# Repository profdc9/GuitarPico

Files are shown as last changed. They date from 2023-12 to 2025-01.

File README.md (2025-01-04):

# Guitar Pico

This is a guitar effects processor based on the Raspberry Pi Pico.  A video of some of the effects is at

https://www.youtube.com/watch?v=15d9mEu2koQ

It includes the following effects:

1.  Noise Gate
2.  Delay 
3.  Room (set up specific echoes at particular delays)
4.  Combine (mix together the signals from several effects)
5.  2nd order Bandpass filter
6.  2nd order Lowpass filter
7.  2nd order Highpass filter
8.  2nd order Allpass filter
9.  Tremolo (amplitude modulated by a low frequency oscillator)
10.  Vibrato (pitch modulated by a low frequency oscillator)
11.  Wah (bandpass filter with center frequency controlled by an external control like a pedal)
12.  AutoWah (bandpass filter with center frequency modulated by a low frequency oscillator)
13.  Envelope (bandpass filter with center frequency modulated by signal amplitude)
14.  Distortion (amplification resulting in saturation of the signal)
15.  Overdrive (selectable threshold for low signal / high signal amplitude gain)
16.  Compressor (amplifies weak signals to equal out overall amplitude of signal)
17.  Ring (ring modulator using low frequency oscillator)
18.  Flanger (pitch modulated by a low frequency oscillator, with feedback and combined with unmodulated signal)
19.  Chorus (pitch modulated by a low frequency oscillator, no feedback and combined with unmodulated signal)
20.  Phaser (signal run through multiple stages of all pass filters, combined with unmodulated signal)
21.  Backwards (plays the last samples backwards for weird swooping effect)
22.  PitchShift (allows shifting the pitch by variable amounts, useful for harmony-like effect)
23.  Whammy (pitch shift based on external control like a pedal)
24.  Octave (rectification and amplification of the signal with extreme distortion)
25.  Sinusoidal Oscillator (built in test signal source)

The effects may be cascaded, to up to 16 in a sequence.  The settings of a particular sequence of effects may be saved in flash memory.  Because the effects are processed one sample at a time in real-time, the lag due to the processing is only 50 microseconds.

There is a stomp pedal which may be used to one of four saved settings, based on which of the four buttons is stomped on.  It does not require power to operate.

The pedal has four potentiometers that may be assigned to control various aspects of effects operation.  There are also two external inputs.  These can be used with the stomp pedal, or with an expression pedal to control aspects of the effects.

There is also a feature to determine the frequency and note being played, to help with tuning a guitar.  Also, if plugged into USB, notes played on the guitar are sent as MIDI events to the PC to turn the guitar into a MIDI instruments.  However, this feature is imperfect (but this useful for tuning).

As well as a MIDI device, the guitar pedal appears as a COM port.  The effect settings may be retrieved from the pedal or programmed into the pedal through this interface using text commands at a prompt.  Type "HELP" for a list of the commands.  For example, typing "CONF 0 0" lists all of the current effects configuration data.  The data is output in the form of the commands used to reprogram the same state back into the device, so these may be directly copied into a text file and pasted back into a terminal to recreate the configuration.

There is also a VGA port that will be used to implement video effects.

The hardware is licensed under CC-BY-SA 4.0 and software under the zlib license (no warranty, yes commercial and noncommercial use), both open source licenses.

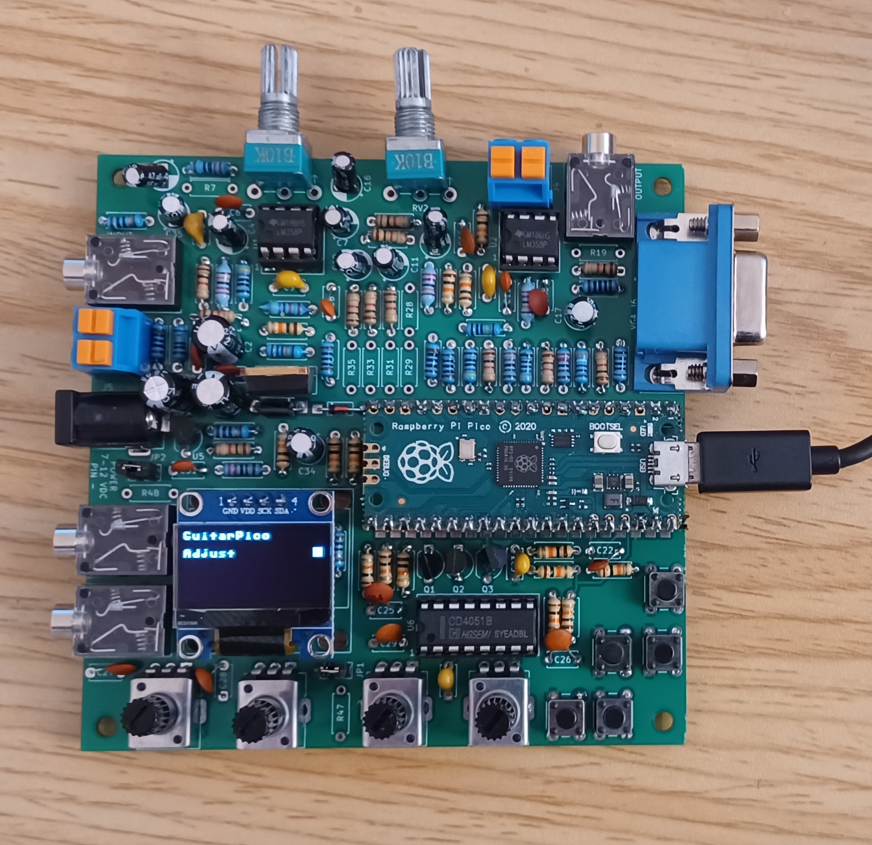
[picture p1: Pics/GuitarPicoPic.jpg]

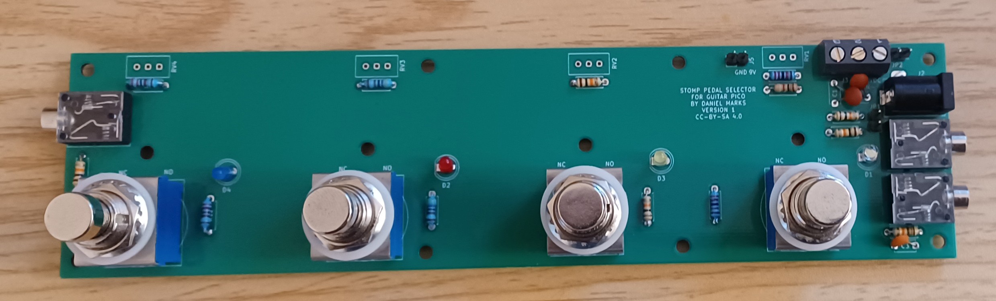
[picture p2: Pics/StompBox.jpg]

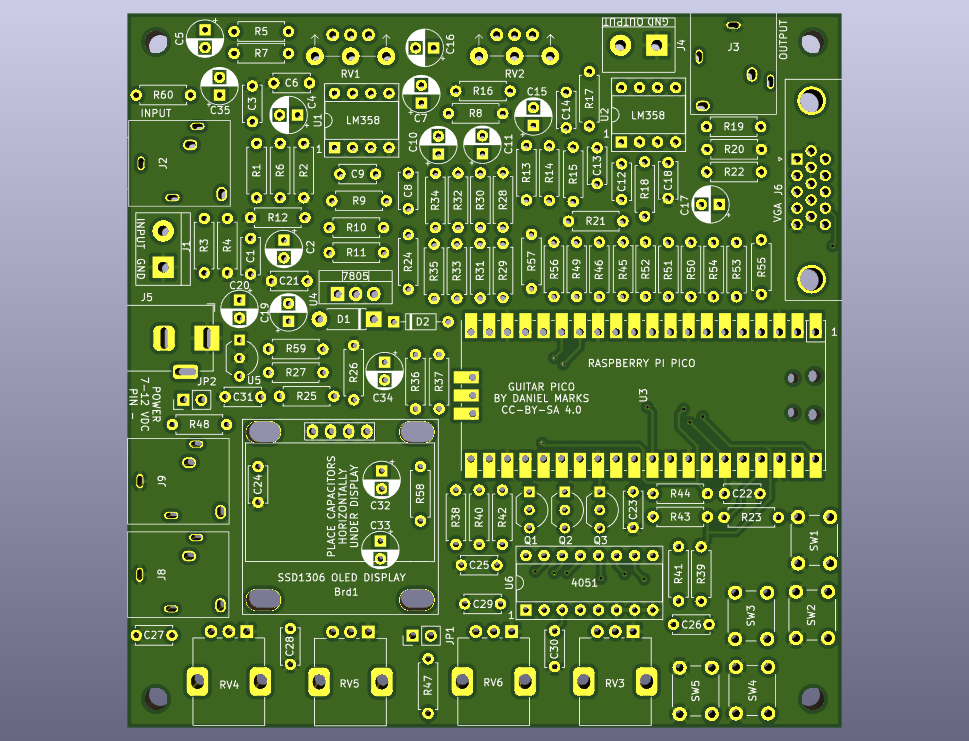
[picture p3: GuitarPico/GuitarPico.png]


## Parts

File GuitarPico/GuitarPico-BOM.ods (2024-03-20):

Source: | D:\projects\GuitarPico\GuitarPico\GuitarPico.kicad_sch
Date: | 03/10/24 08:09 PM
Tool: | Eeschema (6.0.11)
Generator: | C:\Program Files\KiCad\6.0\bin\scripting\plugins/bom_csv_grouped_by_value.py
Component Count: | 132
Individual Components:
Item / lcsc.com | Qty | Reference(s) | Value | LibPart | Footprint | Datasheet
 |  | Brd1 | SSD1306 | SSD1306-128x64_OLED:SSD1306 | GuitarPico:128x64OLED
C2832508 |  | C1 | 100 nF | Device:C_Small | Capacitor_THT:C_Disc_D5.0mm_W2.5mm_P5.00mm | ~
C6718384 |  | C2 | 100 uF | Device:C_Polarized_Small | Capacitor_THT:CP_Radial_D5.0mm_P2.50mm | ~
C2761726 |  | C3 | 1000 pF | Device:C_Small | Capacitor_THT:C_Disc_D5.0mm_W2.5mm_P5.00mm | ~
C106654 |  | C4 | 10 uF | Device:C_Polarized_Small | Capacitor_THT:CP_Radial_D5.0mm_P2.50mm | ~
C106654 |  | C5 | 10 uF | Device:C_Polarized_Small | Capacitor_THT:CP_Radial_D5.0mm_P2.50mm | ~
C2832508 |  | C6 | 100 nF | Device:C_Small | Capacitor_THT:C_Disc_D5.0mm_W2.5mm_P5.00mm | ~
C106654 |  | C7 | 10 uF | Device:C_Polarized_Small | Capacitor_THT:CP_Radial_D5.0mm_P2.50mm | ~
C2887269 |  | C8 | 2200 pF | Device:C_Small | Capacitor_THT:C_Disc_D5.0mm_W2.5mm_P5.00mm | ~
C2896128 |  | C9 | 220 pF | Device:C_Small | Capacitor_THT:C_Disc_D5.0mm_W2.5mm_P5.00mm | ~
C106654 |  | C10 | 10 uF | Device:C_Polarized_Small | Capacitor_THT:CP_Radial_D5.0mm_P2.50mm | ~
C106654 |  | C11 | 10 uF | Device:C_Polarized_Small | Capacitor_THT:CP_Radial_D5.0mm_P2.50mm | ~
C2887269 |  | C12 | 2200 pF | Device:C_Small | Capacitor_THT:C_Disc_D5.0mm_W2.5mm_P5.00mm | ~
C2896103 |  | C13 | 470 pF | Device:C_Small | Capacitor_THT:C_Disc_D5.0mm_W2.5mm_P5.00mm | ~
C2832508 |  | C14 | 100 nF | Device:C_Small | Capacitor_THT:C_Disc_D5.0mm_W2.5mm_P5.00mm | ~
C106654 |  | C15 | 10 uF | Device:C_Polarized_Small | Capacitor_THT:CP_Radial_D5.0mm_P2.50mm | ~
C106654 |  | C16 | 10 uF | Device:C_Polarized_Small | Capacitor_THT:CP_Radial_D5.0mm_P2.50mm | ~
C106654 |  | C17 | 10 uF | Device:C_Polarized_Small | Capacitor_THT:CP_Radial_D5.0mm_P2.50mm | ~
C2832508 |  | C18 | 100 nF | Device:C_Small | Capacitor_THT:C_Disc_D5.0mm_W2.5mm_P5.00mm | ~
C6718384 |  | C19 | 100 uF | Device:C_Polarized_Small | Capacitor_THT:CP_Radial_D5.0mm_P2.50mm | ~
C6718384 |  | C20 | 100 uF | Device:C_Polarized_Small | Capacitor_THT:CP_Radial_D5.0mm_P2.50mm | ~
C2832508 |  | C21 | 100 nF | Device:C_Small | Capacitor_THT:C_Disc_D5.0mm_W2.5mm_P5.00mm | ~
C2761727 |  | C22 | 10 nF | Device:C_Small | Capacitor_THT:C_Disc_D5.0mm_W2.5mm_P5.00mm | ~
C2761725 |  | C23 | 100 pF | Device:C_Small | Capacitor_THT:C_Disc_D5.0mm_W2.5mm_P5.00mm | ~
C2832508 |  | C24 | 100 nF | Device:C_Small | Capacitor_THT:C_Disc_D5.0mm_W2.5mm_P5.00mm | ~
C2832508 |  | C25 | 100 nF | Device:C_Small | Capacitor_THT:C_Disc_D5.0mm_W2.5mm_P5.00mm | ~
C2832508 |  | C26 | 100 nF | Device:C_Small | Capacitor_THT:C_Disc_D5.0mm_W2.5mm_P5.00mm | ~
C2832508 |  | C27 | 100 nF | Device:C_Small | Capacitor_THT:C_Disc_D5.0mm_W2.5mm_P5.00mm | ~
C2832508 |  | C28 | 100 nF | Device:C_Small | Capacitor_THT:C_Disc_D5.0mm_W2.5mm_P5.00mm | ~
C2832508 |  | C29 | 100 nF | Device:C_Small | Capacitor_THT:C_Disc_D5.0mm_W2.5mm_P5.00mm | ~
C2761725 |  | C30 | 100 pF | Device:C_Small | Capacitor_THT:C_Disc_D5.0mm_W2.5mm_P5.00mm | ~
C2761727 |  | C31 | 10 nF | Device:C_Small | Capacitor_THT:C_Disc_D5.0mm_W2.5mm_P5.00mm | ~
C141282 |  | C32 | 220 uF | Device:C_Polarized_Small | Capacitor_THT:CP_Radial_D5.0mm_P2.50mm | ~
C141282 |  | C33 | 220 uF | Device:C_Polarized_Small | Capacitor_THT:CP_Radial_D5.0mm_P2.50mm | ~
C6718384 |  | C34 | 100 uF | Device:C_Polarized_Small | Capacitor_THT:CP_Radial_D5.0mm_P2.50mm | ~
C6718384 |  | C35 | 100 uF | Device:C_Polarized_Small | Capacitor_THT:CP_Radial_D5.0mm_P2.50mm | ~
C5295404 |  | D1 | 1N5819 | Device:D_Schottky | Diode_THT:D_DO-41_SOD81_P7.62mm_Horizontal | ~
C402212 |  | D2 | 1N4148 | Device:D | Diode_THT:D_DO-35_SOD27_P7.62mm_Horizontal | ~
C2915639 |  | J1 | INPUT | Connector_Generic:Conn_01x02 | TerminalBlock:TerminalBlock_bornier-2_P5.08mm | ~
C145814 |  | J2 | INPUT | Connector:AudioJack2_Dual_Ground_Switch | GuitarPico:PJ-3240-35mm-stereo | ~
C145814 |  | J3 | OUTPUT | Connector:AudioJack2_Dual_Ground_Switch | GuitarPico:PJ-3240-35mm-stereo | ~
C2915639 |  | J4 | OUTPUT | Connector_Generic:Conn_01x02 | TerminalBlock:TerminalBlock_bornier-2_P5.08mm | ~
C16214 |  | J5 | Barrel_Jack_Switch | Connector:Barrel_Jack_Switch | Connector_BarrelJack:BarrelJack_Horizontal | ~
C379814 |  | J6 | VGA | Connector:DB15_Female_HighDensity | Connector_Dsub:DSUB-15-HD_Female_Horizontal_P2.29x1.98mm_EdgePinOffset3.03mm_Housed_MountingHolesOffset4.94mm | ~
C145814 |  | J8 | INPUT | Connector:AudioJack2_Dual_Ground_Switch | GuitarPico:PJ-3240-35mm-stereo | ~
C145814 |  | J9 | INPUT | Connector:AudioJack2_Dual_Ground_Switch | GuitarPico:PJ-3240-35mm-stereo | ~
C429959 |  | JP1 | POWER | Jumper:Jumper_2_Open | Connector_PinHeader_2.54mm:PinHeader_1x02_P2.54mm_Vertical | ~
C429959 |  | JP2 | POWER | Jumper:Jumper_2_Open | Connector_PinHeader_2.54mm:PinHeader_1x02_P2.54mm_Vertical | ~
C305395 |  | Q1 | 2N3904 | Transistor_BJT:2N3904 | Package_TO_SOT_THT:TO-92_Inline_Wide | https://www.onsemi.com/pub/Collateral/2N3903-D.PDF
C305395 |  | Q2 | 2N3904 | Transistor_BJT:2N3904 | Package_TO_SOT_THT:TO-92_Inline_Wide | https://www.onsemi.com/pub/Collateral/2N3903-D.PDF
C305395 |  | Q3 | 2N3904 | Transistor_BJT:2N3904 | Package_TO_SOT_THT:TO-92_Inline_Wide | https://www.onsemi.com/pub/Collateral/2N3903-D.PDF
C713997 |  | R1 | 1k | Device:R | Resistor_THT:R_Axial_DIN0207_L6.3mm_D2.5mm_P7.62mm_Horizontal | ~
C119317 (https://www.lcsc.com/product-detail/Through-Hole-Resistors_CCO-Chian-Chia-Elec-MF1-4W-470-1-T_C119317.html) |  | R2 | 470R | Device:R | Resistor_THT:R_Axial_DIN0207_L6.3mm_D2.5mm_P7.62mm_Horizontal | ~
C57438 (https://www.lcsc.com/product-detail/Through-Hole-Resistors_UNI-ROYAL-Uniroyal-Elec-MFR0W4F1000A50_C57438.html) |  | R3 | 100R | Device:R | Resistor_THT:R_Axial_DIN0207_L6.3mm_D2.5mm_P7.62mm_Horizontal | ~
C714052 (https://www.lcsc.com/product-detail/Through-Hole-Resistors_Huaxing-Mechanical-Elec-MF1-4W-1M-1-T52_C714052.html) |  | R4 | 1M | Device:R | Resistor_THT:R_Axial_DIN0207_L6.3mm_D2.5mm_P7.62mm_Horizontal | ~
C120039 (https://www.lcsc.com/product-detail/Through-Hole-Resistors_CCO-Chian-Chia-Elec-CF1-4W-220-5-T_C120039.html) |  | R5 | 220R | Device:R | Resistor_THT:R_Axial_DIN0207_L6.3mm_D2.5mm_P7.62mm_Horizontal | ~
C58662 (https://www.lcsc.com/product-detail/Through-Hole-Resistors_UNI-ROYAL-Uniroyal-Elec-MFR0W4F2203A50_C58662.html) |  | R6 | 220k | Device:R | Resistor_THT:R_Axial_DIN0207_L6.3mm_D2.5mm_P7.62mm_Horizontal | ~
 |  | R7 | NC | Device:R | Resistor_THT:R_Axial_DIN0207_L6.3mm_D2.5mm_P7.62mm_Horizontal | ~
C713997 |  | R8 | 1k | Device:R | Resistor_THT:R_Axial_DIN0207_L6.3mm_D2.5mm_P7.62mm_Horizontal | ~
C176519 (https://www.lcsc.com/product-detail/Through-Hole-Resistors_YAGEO-MFR-25JT-52-47K_C176519.html) |  | R9 | 47k | Device:R | Resistor_THT:R_Axial_DIN0207_L6.3mm_D2.5mm_P7.62mm_Horizontal | ~
C410695 (https://www.lcsc.com/product-detail/Through-Hole-Resistors_TyoHM-RN1-4W10KFT-BA1_C410695.html) |  | R10 | 10k | Device:R | Resistor_THT:R_Axial_DIN0207_L6.3mm_D2.5mm_P7.62mm_Horizontal | ~
C61303 (https://www.lcsc.com/product-detail/Through-Hole-Resistors_UNI-ROYAL-Uniroyal-Elec-CFR0W4J0104A50_C61303.html) |  | R11 | 100k | Device:R | Resistor_THT:R_Axial_DIN0207_L6.3mm_D2.5mm_P7.62mm_Horizontal | ~
C713997 |  | R12 | 1k | Device:R | Resistor_THT:R_Axial_DIN0207_L6.3mm_D2.5mm_P7.62mm_Horizontal | ~
C58662 (https://www.lcsc.com/product-detail/Through-Hole-Resistors_UNI-ROYAL-Uniroyal-Elec-MFR0W4F2203A50_C58662.html) |  | R13 | 220k | Device:R | Resistor_THT:R_Axial_DIN0207_L6.3mm_D2.5mm_P7.62mm_Horizontal | ~
C410695 (https://www.lcsc.com/product-detail/Through-Hole-Resistors_TyoHM-RN1-4W10KFT-BA1_C410695.html) |  | R14 | 10k | Device:R | Resistor_THT:R_Axial_DIN0207_L6.3mm_D2.5mm_P7.62mm_Horizontal | ~
C410695 (https://www.lcsc.com/product-detail/Through-Hole-Resistors_TyoHM-RN1-4W10KFT-BA1_C410695.html) |  | R15 | 10k | Device:R | Resistor_THT:R_Axial_DIN0207_L6.3mm_D2.5mm_P7.62mm_Horizontal | ~
C713997 |  | R16 | 1k | Device:R | Resistor_THT:R_Axial_DIN0207_L6.3mm_D2.5mm_P7.62mm_Horizontal | ~
C410695 (https://www.lcsc.com/product-detail/Through-Hole-Resistors_TyoHM-RN1-4W10KFT-BA1_C410695.html) |  | R17 | 10k | Device:R | Resistor_THT:R_Axial_DIN0207_L6.3mm_D2.5mm_P7.62mm_Horizontal | ~
C58662 (https://www.lcsc.com/product-detail/Through-Hole-Resistors_UNI-ROYAL-Uniroyal-Elec-MFR0W4F2203A50_C58662.html) |  | R18 | 220k | Device:R | Resistor_THT:R_Axial_DIN0207_L6.3mm_D2.5mm_P7.62mm_Horizontal | ~
NC |  | R19 | NC | Device:R | Resistor_THT:R_Axial_DIN0207_L6.3mm_D2.5mm_P7.62mm_Horizontal | ~
C713997 |  | R20 | 1k | Device:R | Resistor_THT:R_Axial_DIN0207_L6.3mm_D2.5mm_P7.62mm_Horizontal | ~
C714052 (https://www.lcsc.com/product-detail/Through-Hole-Resistors_Huaxing-Mechanical-Elec-MF1-4W-1M-1-T52_C714052.html) |  | R21 | 1M | Device:R | Resistor_THT:R_Axial_DIN0207_L6.3mm_D2.5mm_P7.62mm_Horizontal | ~
C57438 (https://www.lcsc.com/product-detail/Through-Hole-Resistors_UNI-ROYAL-Uniroyal-Elec-MFR0W4F1000A50_C57438.html) |  | R22 | 100R | Device:R | Resistor_THT:R_Axial_DIN0207_L6.3mm_D2.5mm_P7.62mm_Horizontal | ~
C410695 (https://www.lcsc.com/product-detail/Through-Hole-Resistors_TyoHM-RN1-4W10KFT-BA1_C410695.html) |  | R23 | 10k | Device:R | Resistor_THT:R_Axial_DIN0207_L6.3mm_D2.5mm_P7.62mm_Horizontal | ~
C57438 (https://www.lcsc.com/product-detail/Through-Hole-Resistors_UNI-ROYAL-Uniroyal-Elec-MFR0W4F1000A50_C57438.html) |  | R24 | 100R | Device:R | Resistor_THT:R_Axial_DIN0207_L6.3mm_D2.5mm_P7.62mm_Horizontal | ~
C58595 (https://www.lcsc.com/product-detail/Through-Hole-Resistors_UNI-ROYAL-Uniroyal-Elec-MFR0W4F2201A50_C58595.html) |  | R25 | 2k2 | Device:R | Resistor_THT:R_Axial_DIN0207_L6.3mm_D2.5mm_P7.62mm_Horizontal | ~
C410695 (https://www.lcsc.com/product-detail/Through-Hole-Resistors_TyoHM-RN1-4W10KFT-BA1_C410695.html) |  | R26 | 10k | Device:R | Resistor_THT:R_Axial_DIN0207_L6.3mm_D2.5mm_P7.62mm_Horizontal | ~
C713997 |  | R27 | 1k | Device:R | Resistor_THT:R_Axial_DIN0207_L6.3mm_D2.5mm_P7.62mm_Horizontal | ~
C119330 (https://www.lcsc.com/product-detail/Through-Hole-Resistors_CCO-Chian-Chia-Elec-MF1-4W-2K-1-T_C119330.html) |  | R28 | 2k | Device:R | Resistor_THT:R_Axial_DIN0207_L6.3mm_D2.5mm_P7.62mm_Horizontal | ~
C119330 (https://www.lcsc.com/product-detail/Through-Hole-Resistors_CCO-Chian-Chia-Elec-MF1-4W-2K-1-T_C119330.html) |  | R29 | 2k | Device:R | Resistor_THT:R_Axial_DIN0207_L6.3mm_D2.5mm_P7.62mm_Horizontal | ~
C713997 |  | R30 | 1k | Device:R | Resistor_THT:R_Axial_DIN0207_L6.3mm_D2.5mm_P7.62mm_Horizontal | ~
C119330 (https://www.lcsc.com/product-detail/Through-Hole-Resistors_CCO-Chian-Chia-Elec-MF1-4W-2K-1-T_C119330.html) |  | R31 | 2k | Device:R | Resistor_THT:R_Axial_DIN0207_L6.3mm_D2.5mm_P7.62mm_Horizontal | ~
C713997 |  | R32 | 1k | Device:R | Resistor_THT:R_Axial_DIN0207_L6.3mm_D2.5mm_P7.62mm_Horizontal | ~
C119330 (https://www.lcsc.com/product-detail/Through-Hole-Resistors_CCO-Chian-Chia-Elec-MF1-4W-2K-1-T_C119330.html) |  | R33 | 2k | Device:R | Resistor_THT:R_Axial_DIN0207_L6.3mm_D2.5mm_P7.62mm_Horizontal | ~
C713997 |  | R34 | 1k | Device:R | Resistor_THT:R_Axial_DIN0207_L6.3mm_D2.5mm_P7.62mm_Horizontal | ~
C119330 (https://www.lcsc.com/product-detail/Through-Hole-Resistors_CCO-Chian-Chia-Elec-MF1-4W-2K-1-T_C119330.html) |  | R35 | 2k | Device:R | Resistor_THT:R_Axial_DIN0207_L6.3mm_D2.5mm_P7.62mm_Horizontal | ~
C410695 (https://www.lcsc.com/product-detail/Through-Hole-Resistors_TyoHM-RN1-4W10KFT-BA1_C410695.html) |  | R36 | 10k | Device:R | Resistor_THT:R_Axial_DIN0207_L6.3mm_D2.5mm_P7.62mm_Horizontal | ~
C410695 (https://www.lcsc.com/product-detail/Through-Hole-Resistors_TyoHM-RN1-4W10KFT-BA1_C410695.html) |  | R37 | 10k | Device:R | Resistor_THT:R_Axial_DIN0207_L6.3mm_D2.5mm_P7.62mm_Horizontal | ~
C410695 (https://www.lcsc.com/product-detail/Through-Hole-Resistors_TyoHM-RN1-4W10KFT-BA1_C410695.html) |  | R38 | 10k | Device:R | Resistor_THT:R_Axial_DIN0207_L6.3mm_D2.5mm_P7.62mm_Horizontal | ~
C410695 (https://www.lcsc.com/product-detail/Through-Hole-Resistors_TyoHM-RN1-4W10KFT-BA1_C410695.html) |  | R39 | 10k | Device:R | Resistor_THT:R_Axial_DIN0207_L6.3mm_D2.5mm_P7.62mm_Horizontal | ~
C410695 (https://www.lcsc.com/product-detail/Through-Hole-Resistors_TyoHM-RN1-4W10KFT-BA1_C410695.html) |  | R40 | 10k | Device:R | Resistor_THT:R_Axial_DIN0207_L6.3mm_D2.5mm_P7.62mm_Horizontal | ~
C410695 (https://www.lcsc.com/product-detail/Through-Hole-Resistors_TyoHM-RN1-4W10KFT-BA1_C410695.html) |  | R41 | 10k | Device:R | Resistor_THT:R_Axial_DIN0207_L6.3mm_D2.5mm_P7.62mm_Horizontal | ~
C410695 (https://www.lcsc.com/product-detail/Through-Hole-Resistors_TyoHM-RN1-4W10KFT-BA1_C410695.html) |  | R42 | 10k | Device:R | Resistor_THT:R_Axial_DIN0207_L6.3mm_D2.5mm_P7.62mm_Horizontal | ~
C410695 (https://www.lcsc.com/product-detail/Through-Hole-Resistors_TyoHM-RN1-4W10KFT-BA1_C410695.html) |  | R43 | 10k | Device:R | Resistor_THT:R_Axial_DIN0207_L6.3mm_D2.5mm_P7.62mm_Horizontal | ~
C410695 (https://www.lcsc.com/product-detail/Through-Hole-Resistors_TyoHM-RN1-4W10KFT-BA1_C410695.html) |  | R44 | 10k | Device:R | Resistor_THT:R_Axial_DIN0207_L6.3mm_D2.5mm_P7.62mm_Horizontal | ~
C58595 (https://www.lcsc.com/product-detail/Through-Hole-Resistors_UNI-ROYAL-Uniroyal-Elec-MFR0W4F2201A50_C58595.html) |  | R45 | 2k2 | Device:R | Resistor_THT:R_Axial_DIN0207_L6.3mm_D2.5mm_P7.62mm_Horizontal | ~
C713997 |  | R46 | 1k | Device:R | Resistor_THT:R_Axial_DIN0207_L6.3mm_D2.5mm_P7.62mm_Horizontal | ~
NC |  | R47 | NC | Device:R | Resistor_THT:R_Axial_DIN0207_L6.3mm_D2.5mm_P7.62mm_Horizontal | ~
NC |  | R48 | NC | Device:R | Resistor_THT:R_Axial_DIN0207_L6.3mm_D2.5mm_P7.62mm_Horizontal | ~
C119317 (https://www.lcsc.com/product-detail/Through-Hole-Resistors_CCO-Chian-Chia-Elec-MF1-4W-470-1-T_C119317.html) |  | R49 | 470R | Device:R | Resistor_THT:R_Axial_DIN0207_L6.3mm_D2.5mm_P7.62mm_Horizontal | ~
C58595 (https://www.lcsc.com/product-detail/Through-Hole-Resistors_UNI-ROYAL-Uniroyal-Elec-MFR0W4F2201A50_C58595.html) |  | R50 | 2k2 | Device:R | Resistor_THT:R_Axial_DIN0207_L6.3mm_D2.5mm_P7.62mm_Horizontal | ~
C713997 |  | R51 | 1k | Device:R | Resistor_THT:R_Axial_DIN0207_L6.3mm_D2.5mm_P7.62mm_Horizontal | ~
C119317 (https://www.lcsc.com/product-detail/Through-Hole-Resistors_CCO-Chian-Chia-Elec-MF1-4W-470-1-T_C119317.html) |  | R52 | 470R | Device:R | Resistor_THT:R_Axial_DIN0207_L6.3mm_D2.5mm_P7.62mm_Horizontal | ~
C713997 |  | R53 | 1k | Device:R | Resistor_THT:R_Axial_DIN0207_L6.3mm_D2.5mm_P7.62mm_Horizontal | ~
C173010 (https://www.lcsc.com/product-detail/Through-Hole-Resistors_YAGEO-MFR-25FTE52-390R_C173010.html) |  | R54 | 390R | Device:R | Resistor_THT:R_Axial_DIN0207_L6.3mm_D2.5mm_P7.62mm_Horizontal | ~
C58668 (https://www.lcsc.com/product-detail/Through-Hole-Resistors_UNI-ROYAL-Uniroyal-Elec-MFR0W4F1500A50_C58668.html) |  | R55 | 150R | Device:R | Resistor_THT:R_Axial_DIN0207_L6.3mm_D2.5mm_P7.62mm_Horizontal | ~
C57438 (https://www.lcsc.com/product-detail/Through-Hole-Resistors_UNI-ROYAL-Uniroyal-Elec-MFR0W4F1000A50_C57438.html) |  | R56 | 100R | Device:R | Resistor_THT:R_Axial_DIN0207_L6.3mm_D2.5mm_P7.62mm_Horizontal | ~
C57438 (https://www.lcsc.com/product-detail/Through-Hole-Resistors_UNI-ROYAL-Uniroyal-Elec-MFR0W4F1000A50_C57438.html) |  | R57 | 100R | Device:R | Resistor_THT:R_Axial_DIN0207_L6.3mm_D2.5mm_P7.62mm_Horizontal | ~
C119282 (https://www.lcsc.com/product-detail/Through-Hole-Resistors_CCO-Chian-Chia-Elec-MF1-4W-10-1-T_C119282.html) |  | R58 | 10R | Device:R | Resistor_THT:R_Axial_DIN0207_L6.3mm_D2.5mm_P7.62mm_Horizontal | ~
C119282 (https://www.lcsc.com/product-detail/Through-Hole-Resistors_CCO-Chian-Chia-Elec-MF1-4W-10-1-T_C119282.html) |  | R59 | 10R | Device:R | Resistor_THT:R_Axial_DIN0207_L6.3mm_D2.5mm_P7.62mm_Horizontal | ~
C119282 (https://www.lcsc.com/product-detail/Through-Hole-Resistors_CCO-Chian-Chia-Elec-MF1-4W-10-1-T_C119282.html) |  | R60 | 10R | Device:R | Resistor_THT:R_Axial_DIN0207_L6.3mm_D2.5mm_P7.62mm_Horizontal | ~
C470717 |  | RV1 | 10k | Device:R_Potentiometer | GuitarPico:Potentiometer_Big_Small_Combined | ~
C470717 |  | RV2 | 10k | Device:R_Potentiometer | GuitarPico:Potentiometer_Big_Small_Combined | ~
C209779 |  | RV3 | 10k | Device:R_Potentiometer | Potentiometer_THT:Potentiometer_Alps_RK09K_Single_Vertical | ~
C209779 |  | RV4 | 10k | Device:R_Potentiometer | Potentiometer_THT:Potentiometer_Alps_RK09K_Single_Vertical | ~
C209779 |  | RV5 | 10k | Device:R_Potentiometer | Potentiometer_THT:Potentiometer_Alps_RK09K_Single_Vertical | ~
C209779 |  | RV6 | 10k | Device:R_Potentiometer | Potentiometer_THT:Potentiometer_Alps_RK09K_Single_Vertical | ~
C319408 |  | SW1 | SW_Push | Switch:SW_Push | Button_Switch_THT:SW_PUSH_6mm | ~
C319408 |  | SW2 | SW_Push | Switch:SW_Push | Button_Switch_THT:SW_PUSH_6mm | ~
C319408 |  | SW3 | SW_Push | Switch:SW_Push | Button_Switch_THT:SW_PUSH_6mm | ~
C319408 |  | SW4 | SW_Push | Switch:SW_Push | Button_Switch_THT:SW_PUSH_6mm | ~
C319408 |  | SW5 | SW_Push | Switch:SW_Push | Button_Switch_THT:SW_PUSH_6mm | ~
C434570,C72124 |  | U1 | LM358 | Amplifier_Operational:LM358 | Package_DIP:DIP-8_W7.62mm_Socket | http://www.ti.com/lit/ds/symlink/lm2904-n.pdf
C434570,C72124 |  | U2 | LM358 | Amplifier_Operational:LM358 | Package_DIP:DIP-8_W7.62mm_Socket | http://www.ti.com/lit/ds/symlink/lm2904-n.pdf
C343636 |  | U3 | Pico | MCU_RaspberryPi_and_Boards:Pico | GuitarPico:RPi_Pico_SMD_TH
C7432180 |  | U4 | LM7805_TO220 | Regulator_Linear:LM7805_TO220 | Package_TO_SOT_THT:TO-220-3_Vertical | https://www.onsemi.cn/PowerSolutions/document/MC7800-D.PDF
C5155530 |  | U5 | TL431LP | Reference_Voltage:TL431LP | Package_TO_SOT_THT:TO-92_Inline_Wide | http://www.ti.com/lit/ds/symlink/tl431.pdf
C507164,C72115 |  | U6 | 4051 | 4xxx:4051 | Package_DIP:DIP-16_W7.62mm_Socket | http://www.intersil.com/content/dam/Intersil/documents/cd40/cd4051bms-52bms-53bms.pdf

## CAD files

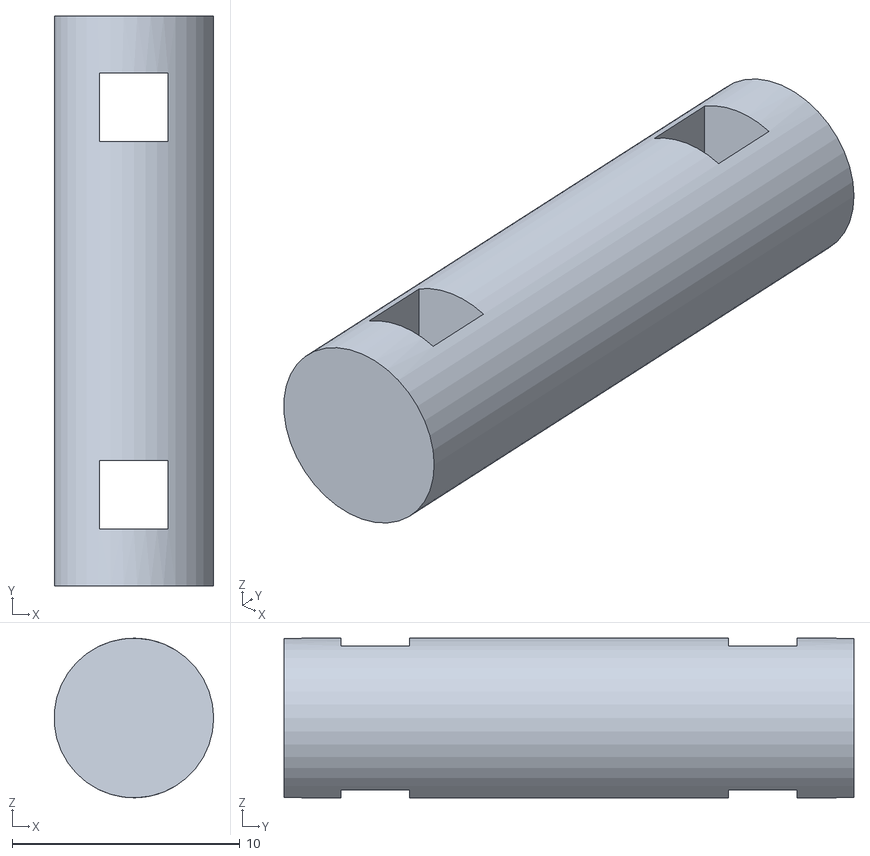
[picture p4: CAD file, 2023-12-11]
CAD/GuitarPedal-PivotRodRight.stl
6.99 x 25.0 x 7.00

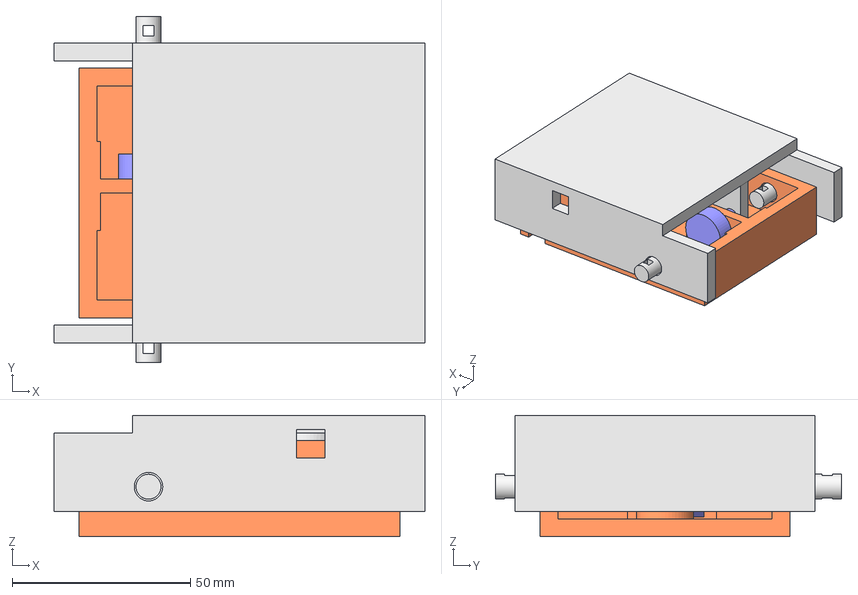
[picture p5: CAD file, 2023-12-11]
CAD/GuitarPedal.FCStd
104.0 x 97.0 x 34.0 mm
PivotRodLeft
PivotRodRight
Potentiometer
TopPedal
BottomPedal

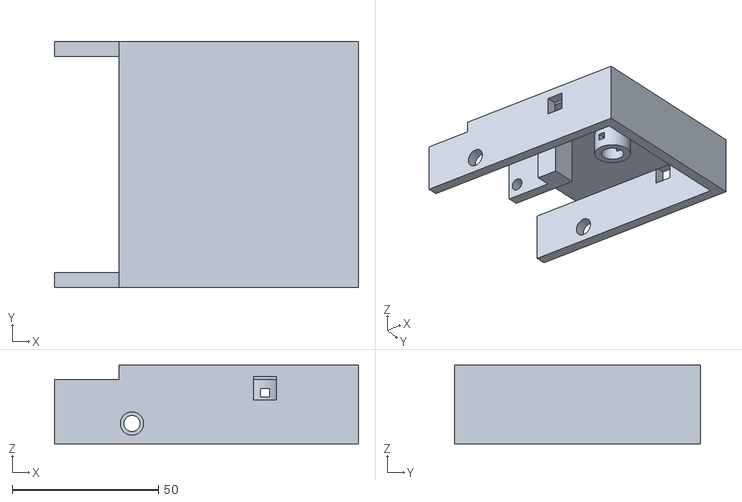
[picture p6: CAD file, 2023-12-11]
CAD/GuitarPedal-TopPedal.stl
104.0 x 84.0 x 27.0

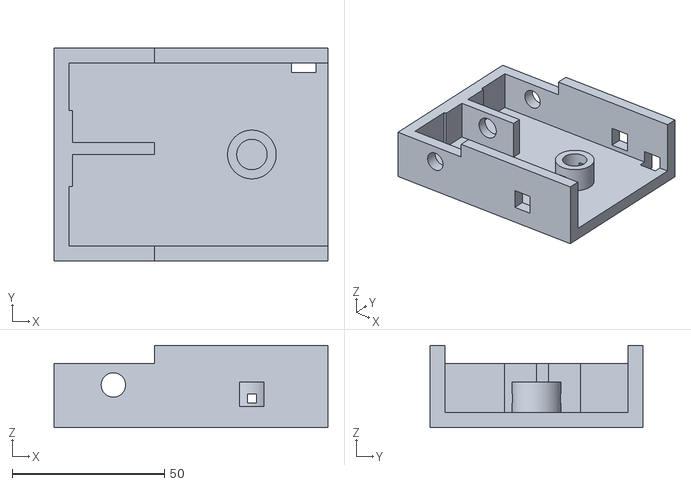
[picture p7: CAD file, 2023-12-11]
CAD/GuitarPedal-BottomPedal.stl
90.0 x 70.0 x 27.0

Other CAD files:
CAD/GuitarPedal-PivotRodLeft.stl

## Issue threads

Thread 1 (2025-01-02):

Build fails - Update needed?

engrjones, 2025-01-02:
I recently tried to build the solution and ran into some issues. I got it to work with some simple fixes. It's possible I just didn't have the right environment or something, but here's what I did, in case it's helpful:

1. Add `#include "hardware/clocks.h"` to main.cpp and vga_mode.cpp. The solution would not build without this addition.
2. In dsp.c Line 33, change `"Waves.h"` to `"waves.h"`.

profdc9, 2025-01-03:
I recently made those changes with the new Development Tools and I will
push them up shortly.   Also the TrebleSynth has the fixes too.

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

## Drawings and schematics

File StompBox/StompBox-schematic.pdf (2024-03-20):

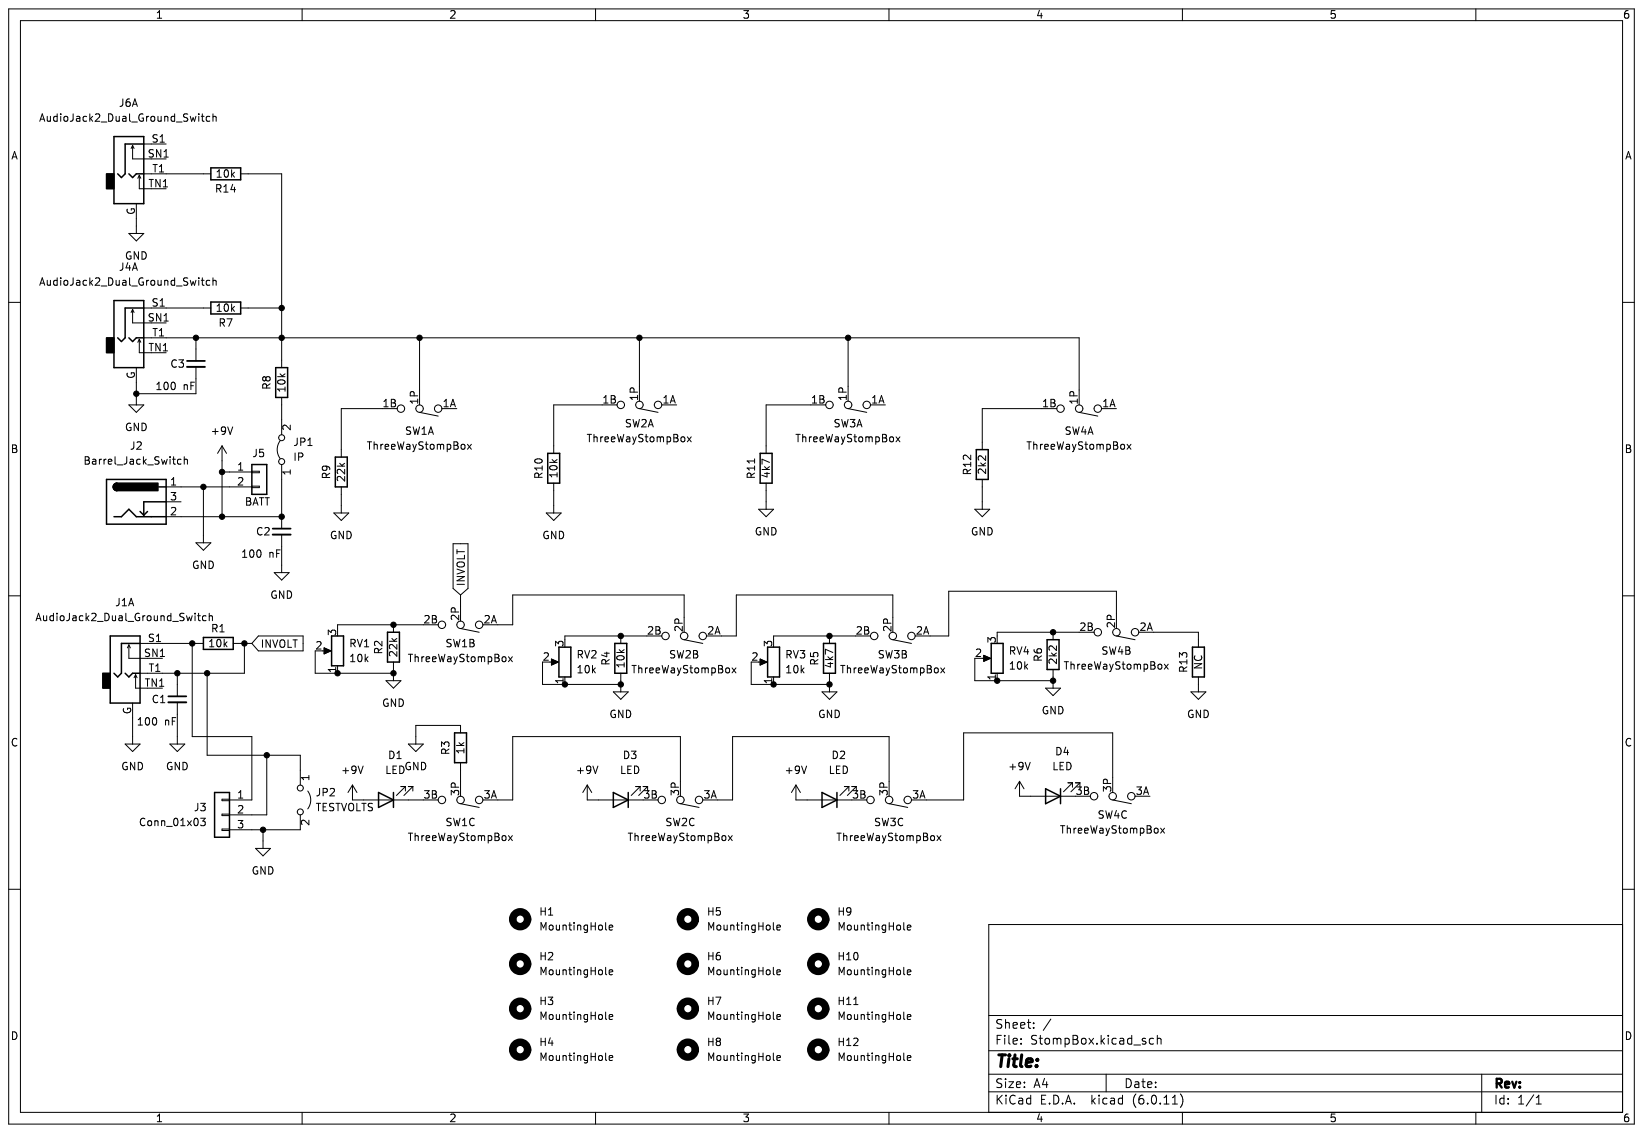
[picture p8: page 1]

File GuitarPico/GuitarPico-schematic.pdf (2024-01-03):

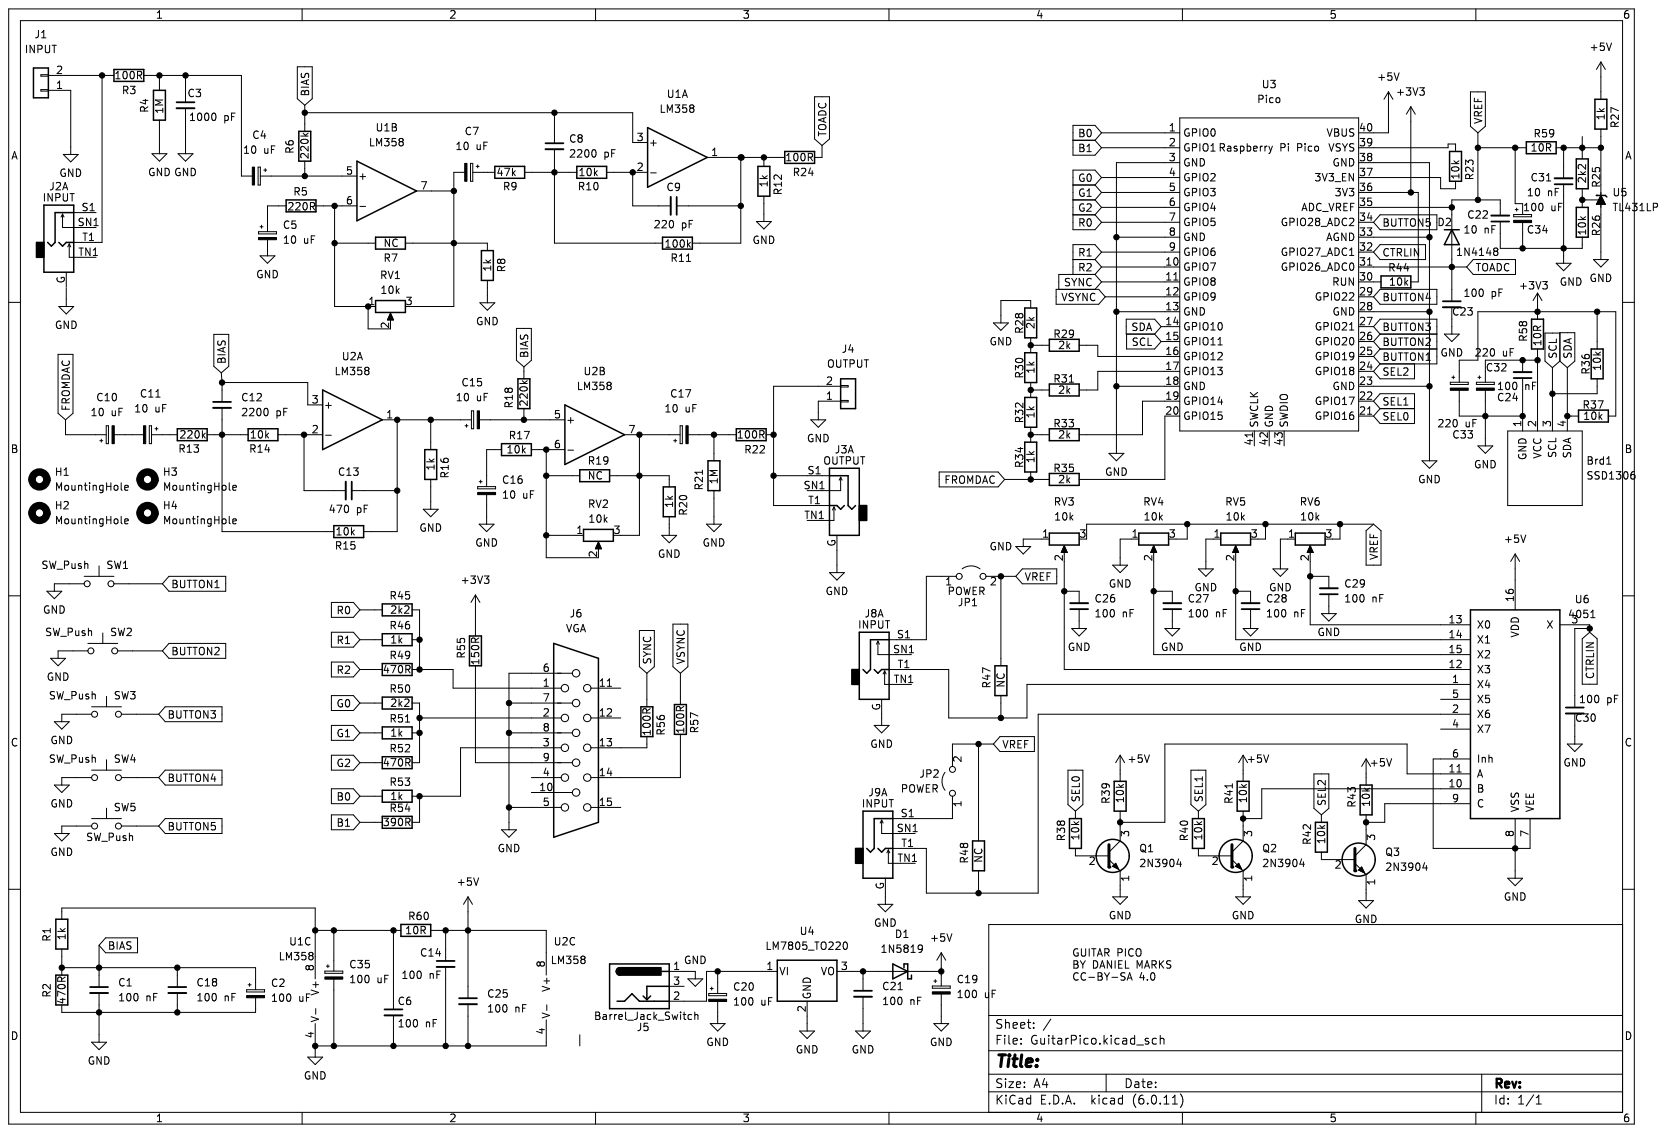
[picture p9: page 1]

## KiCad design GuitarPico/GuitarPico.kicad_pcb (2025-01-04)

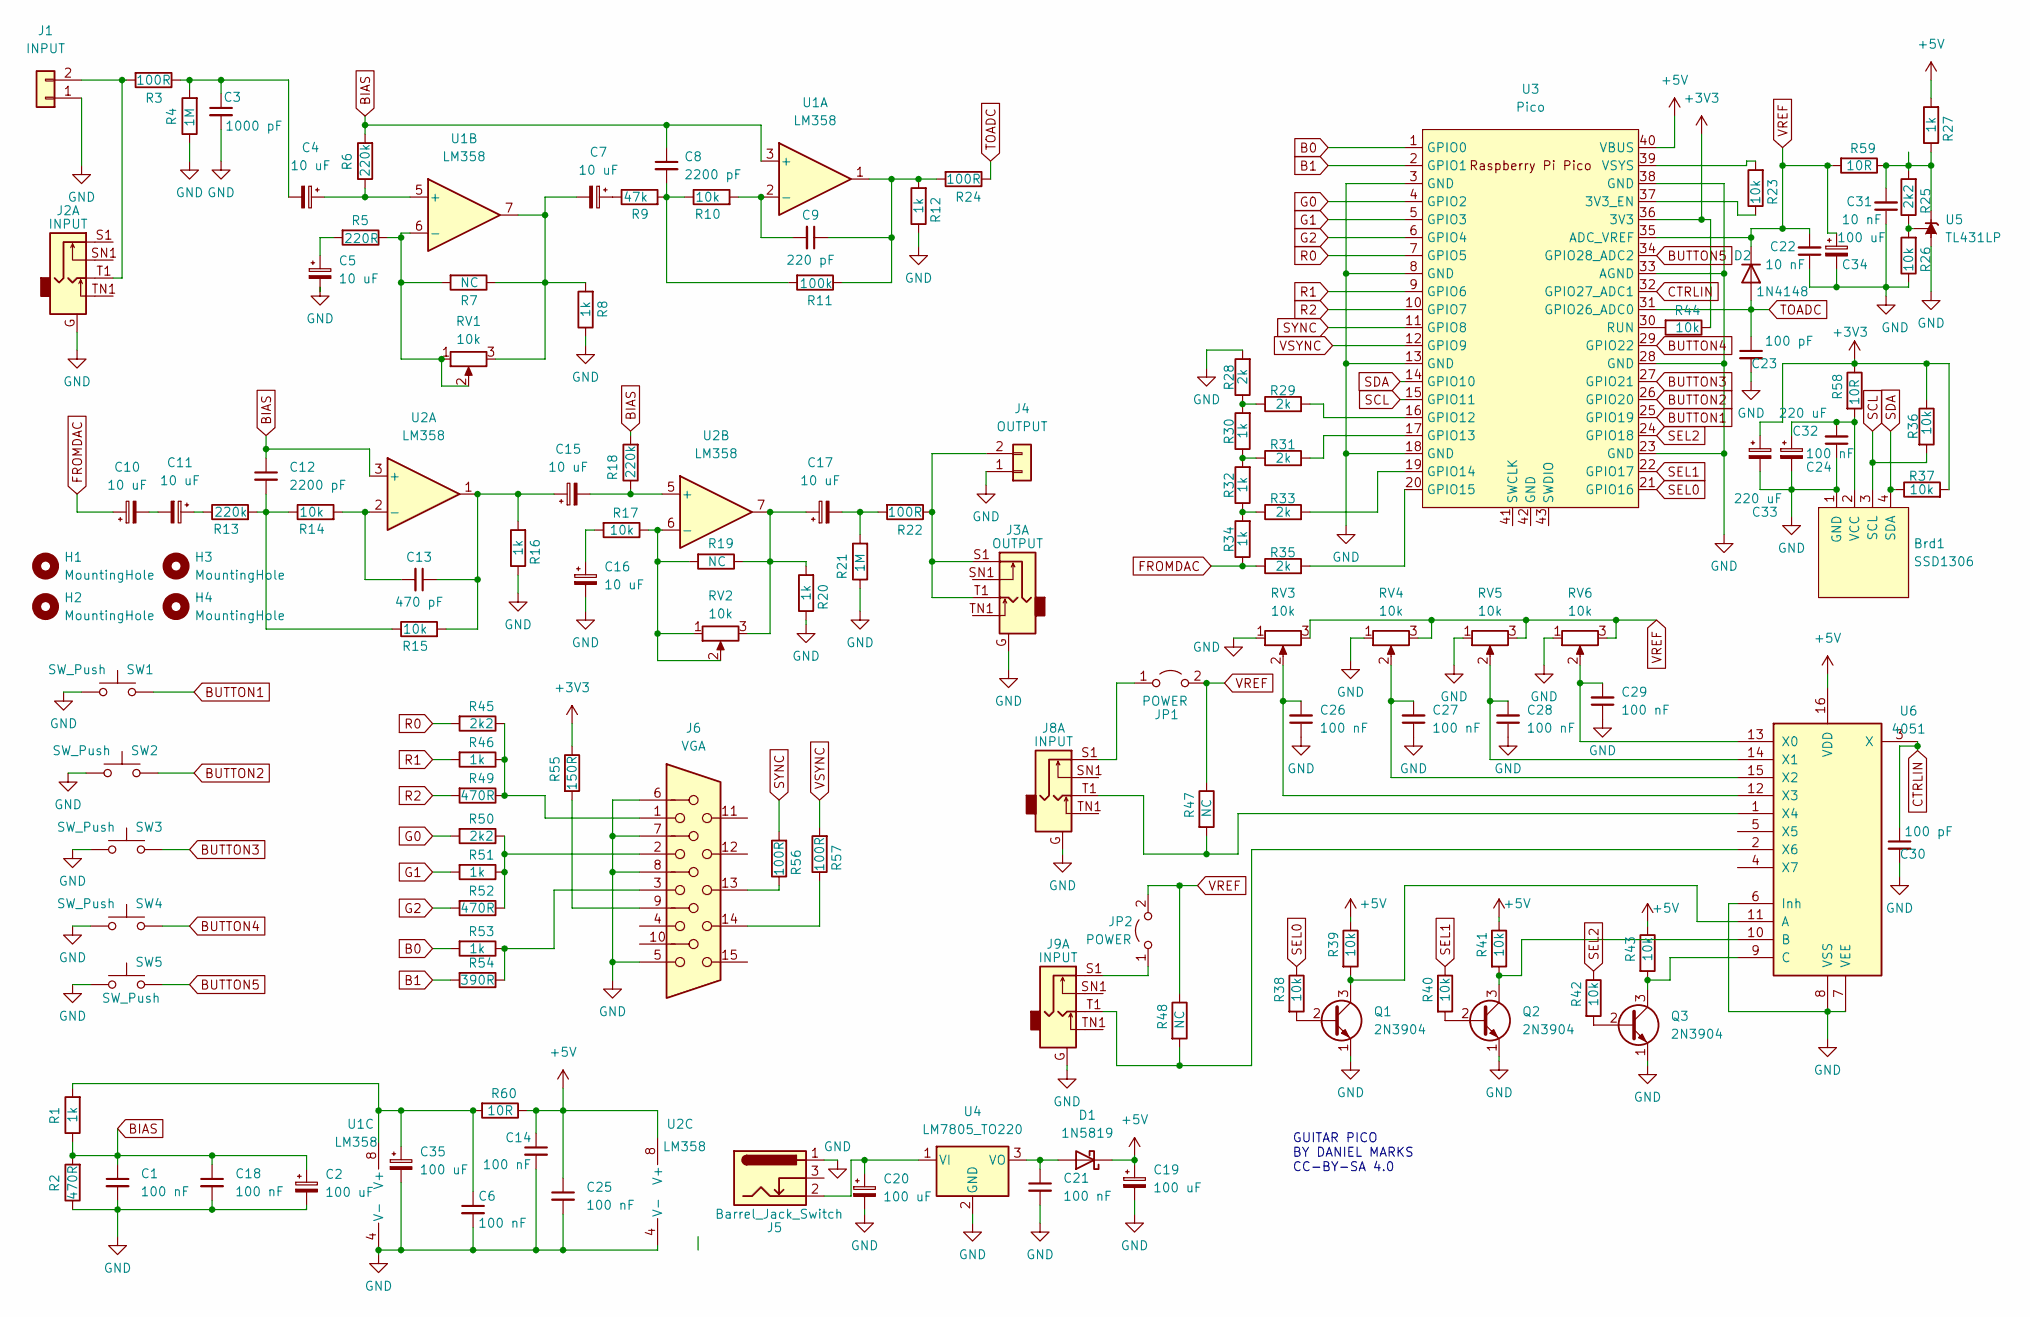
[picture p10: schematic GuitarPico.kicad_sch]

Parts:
Brd1: SSD1306; 128x64OLED
C1, C6, C14, C18, C21, C24, C25, C26, C27, C28, C29: 100 nF; C_Disc_D5.0mm_W2.5mm_P5.00mm
C2, C19, C20, C34, C35: 100 uF; CP_Radial_D5.0mm_P2.50mm
C3: 1000 pF; C_Disc_D5.0mm_W2.5mm_P5.00mm
C4, C5, C7, C10, C11, C15, C16, C17: 10 uF; CP_Radial_D5.0mm_P2.50mm
C8, C12: 2200 pF; C_Disc_D5.0mm_W2.5mm_P5.00mm
C9: 220 pF; C_Disc_D5.0mm_W2.5mm_P5.00mm
C13: 470 pF; C_Disc_D5.0mm_W2.5mm_P5.00mm
C22, C31: 10 nF; C_Disc_D5.0mm_W2.5mm_P5.00mm
C23, C30: 100 pF; C_Disc_D5.0mm_W2.5mm_P5.00mm
C32, C33: 220 uF; CP_Radial_D5.0mm_P2.50mm
D1: 1N5819; D_DO-41_SOD81_P7.62mm_Horizontal
D2: 1N4148; D_DO-35_SOD27_P7.62mm_Horizontal
H1, H2, H3, H4: MountingHole; MountingHole_3.2mm_M3
J1: INPUT; TerminalBlock_bornier-2_P5.08mm
J2, J8, J9: INPUT; PJ-3240-35mm-stereo
J3: OUTPUT; PJ-3240-35mm-stereo
J4: OUTPUT; TerminalBlock_bornier-2_P5.08mm
J5: Barrel_Jack_Switch; BarrelJack_Horizontal
J6: VGA; DSUB-15-HD_Female_Horizontal_P2.29x1.98mm_EdgePinOffset3.03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
JP1, JP2: POWER; PinHeader_1x02_P2.54mm_Vertical
Q1, Q2, Q3: 2N3904; TO-92_Inline_Wide
R1, R8, R12, R16, R20, R27, R30, R32, R34, R46, R51, R53: 1k; R_Axial_DIN0207_L6.3mm_D2.5mm_P7.62mm_Horizontal
R2, R49, R52: 470R; R_Axial_DIN0207_L6.3mm_D2.5mm_P7.62mm_Horizontal
R3, R22, R24, R56, R57: 100R; R_Axial_DIN0207_L6.3mm_D2.5mm_P7.62mm_Horizontal
R4, R21: 1M; R_Axial_DIN0207_L6.3mm_D2.5mm_P7.62mm_Horizontal
R5: 220R; R_Axial_DIN0207_L6.3mm_D2.5mm_P7.62mm_Horizontal
R6, R13, R18: 220k; R_Axial_DIN0207_L6.3mm_D2.5mm_P7.62mm_Horizontal
R7, R19, R47, R48: NC; R_Axial_DIN0207_L6.3mm_D2.5mm_P7.62mm_Horizontal
R9: 47k; R_Axial_DIN0207_L6.3mm_D2.5mm_P7.62mm_Horizontal
R10, R14, R15, R17, R23, R26, R36, R37, R38, R39, R40, R41, R42, R43, R44: 10k; R_Axial_DIN0207_L6.3mm_D2.5mm_P7.62mm_Horizontal
R11: 100k; R_Axial_DIN0207_L6.3mm_D2.5mm_P7.62mm_Horizontal
R25, R45, R50: 2k2; R_Axial_DIN0207_L6.3mm_D2.5mm_P7.62mm_Horizontal
R28, R29, R31, R33, R35: 2k; R_Axial_DIN0207_L6.3mm_D2.5mm_P7.62mm_Horizontal
R54: 390R; R_Axial_DIN0207_L6.3mm_D2.5mm_P7.62mm_Horizontal
R55: 150R; R_Axial_DIN0207_L6.3mm_D2.5mm_P7.62mm_Horizontal
R58, R59, R60: 10R; R_Axial_DIN0207_L6.3mm_D2.5mm_P7.62mm_Horizontal
RV1, RV2: 10k; Potentiometer_Big_Small_Combined
RV3, RV4, RV5, RV6: 10k; Potentiometer_Alps_RK09K_Single_Vertical
SW1, SW2, SW3, SW4, SW5: SW_Push; SW_PUSH_6mm
U1, U2: LM358; DIP-8_W7.62mm_Socket
U3: Pico; RPi_Pico_SMD_TH
U4: LM7805_TO220; TO-220-3_Vertical
U5: TL431LP; TO-92_Inline_Wide
U6: 4051; DIP-16_W7.62mm_Socket

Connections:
+3V3: C33.1, R36.1, R37.2, R44.1, R55.1, R58.1, U3.36 (3V3)
+5V: C14.1, C19.1, C25.1, D1.1 (K), R27.2, R39.1, R41.1, R43.1, R60.1, U2.8 (V+), U3.40 (VBUS), U6.16 (VDD)
B0: R53.2, U3.1 (GPIO0)
B1: R54.2, U3.2 (GPIO1)
BIAS: C1.1, C2.1, C8.1, C12.1, C18.1, R1.1, R2.2, R6.2, R18.2, U1.3 (+), U2.3 (+)
BUTTON1: SW1.2, U3.25 (GPIO19)
BUTTON2: SW2.2, U3.26 (GPIO20)
BUTTON3: SW3.2, U3.27 (GPIO21)
BUTTON4: SW4.2, U3.29 (GPIO22)
BUTTON5: SW5.2, U3.34 (GPIO28_ADC2)
CTRLIN: C30.1, U3.32 (GPIO27_ADC1), U6.3 (X)
FROMDAC: C10.1, R34.1, R35.1
G0: R50.2, U3.4 (GPIO2)
G1: R51.2, U3.5 (GPIO3)
G2: R52.2, U3.6 (GPIO4)
GND: Brd1.1 (GND), C1.2, C2.2, C3.2, C5.2, C6.2, C14.2, C16.2, C18.2, C19.2, C20.2, C21.2, C22.1, C23.2, C24.1, C25.2, C26.1, C27.1, C28.1, C29.1, C30.2, C31.1, C32.2, C33.2, C34.2, C35.2, J1.1, J2.G, J3.G, J4.1, J5.1, J6.5, J6.6, J6.7, J6.8, J8.G, J9.G, Q1.1 (E), Q2.1 (E), Q3.1 (E), R2.1, R4.1, R8.1, R12.1, R16.1, R20.1, R21.1, R26.1, R28.2, RV3.1, RV4.1, RV5.1, RV6.1, SW1.1, SW2.1, SW3.1, SW4.1, SW5.1, U1.4 (V-), U2.4 (V-), U3.3 (GND), U3.8 (GND), U3.13 (GND), U3.18 (GND), U3.23 (GND), U3.28 (GND), U3.33 (AGND), U3.38 (GND), U4.2 (GND), U5.2 (A), U6.6 (Inh), U6.7 (VEE), U6.8 (VSS)
unnamed: Brd1.2 (VCC), C24.2, C32.1, R58.2
unnamed: C4.1, R6.1, U1.5 (+)
unnamed: C3.1, C4.2, R3.1, R4.2
unnamed: C5.1, R5.2
unnamed: C7.1, R9.1
unnamed: C8.2, R9.2, R10.1, R11.2
unnamed: C9.1, R11.1, R12.2, R24.2, U1.1
unnamed: C9.2, R10.2, U1.2 (-)
unnamed: C10.2, C11.2
unnamed: C11.1, R13.1
unnamed: C12.2, R13.2, R14.1, R15.1
unnamed: C13.1, C15.1, R15.2, R16.2, U2.1
unnamed: C13.2, R14.2, U2.2 (-)
unnamed: C15.2, R18.1, U2.5 (+)
unnamed: C16.1, R17.2
unnamed: C17.1, R19.1, R20.2, RV2.3, U2.7
unnamed: C17.2, R21.2, R22.2
unnamed: C20.1, J5.2, U4.1 (VI)
unnamed: C21.1, D1.2 (A), U4.3 (VO)
unnamed: C26.2, RV3.2, U6.12 (X3)
unnamed: C27.2, RV4.2, U6.15 (X2)
unnamed: C28.2, RV5.2, U6.14 (X1)
unnamed: C29.2, RV6.2, U6.13 (X0)
unnamed: C31.2, R25.2, R27.1, R59.1, U5.3 (K)
unnamed: C6.1, C35.1, R1.2, R60.2, U1.8 (V+)
unnamed: J1.2, J2.T1, R3.2
unnamed: J3.S1, J3.T1, J4.2, R22.1
unnamed: J6.1, R45.1, R46.1, R49.1
unnamed: J6.2, R50.1, R51.1, R52.1
unnamed: J6.3, R53.1, R54.1
unnamed: J6.9, R55.2
unnamed: J6.13, R56.1
unnamed: J6.14, R57.1
unnamed: J8.S1, JP1.1 (A)
unnamed: J8.T1, R47.2, U6.1 (X4)
unnamed: J9.S1, JP2.1 (A)
unnamed: J9.T1, R48.2, U6.2 (X6)
unnamed: Q1.2 (B), R38.2
unnamed: Q1.3 (C), R39.2, U6.11 (A)
unnamed: Q2.2 (B), R40.2
unnamed: Q2.3 (C), R41.2, U6.10 (B)
unnamed: Q3.2 (B), R42.2
unnamed: Q3.3 (C), R43.2, U6.9 (C)
unnamed: R5.1, R7.2, RV1.1, RV1.2, U1.6 (-)
unnamed: C7.2, R7.1, R8.2, RV1.3, U1.7
unnamed: R17.1, R19.2, RV2.1, RV2.2, U2.6 (-)
unnamed: R23.1, U3.37 (3V3_EN)
unnamed: R23.2, U3.39 (VSYS)
unnamed: R25.1, R26.2, U5.1 (REF)
unnamed: R28.1, R29.1, R30.2
unnamed: R29.2, U3.16 (GPIO12)
unnamed: R30.1, R31.1, R32.2
unnamed: R31.2, U3.17 (GPIO13)
unnamed: R32.1, R33.1, R34.2
unnamed: R33.2, U3.19 (GPIO14)
unnamed: R35.2, U3.20 (GPIO15)
unnamed: R44.2, U3.30 (RUN)
R0: R45.2, U3.7 (GPIO5)
R1: R46.2, U3.9 (GPIO6)
R2: R49.2, U3.10 (GPIO7)
SCL: Brd1.3 (SCL), R36.2, U3.15 (GPIO11)
SDA: Brd1.4 (SDA), R37.1, U3.14 (GPIO10)
SEL0: R38.1, U3.21 (GPIO16)
SEL1: R40.1, U3.22 (GPIO17)
SEL2: R42.1, U3.24 (GPIO18)
SYNC: R56.2, U3.11 (GPIO8)
TOADC: C23.1, D2.2 (A), R24.1, U3.31 (GPIO26_ADC0)
VREF: C22.2, C34.1, D2.1 (K), JP1.2 (B), JP2.2 (B), R47.1, R48.1, R59.2, RV3.3, RV4.3, RV5.3, RV6.3, U3.35 (ADC_VREF)
VSYNC: R57.2, U3.12 (GPIO9)

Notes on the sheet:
GUITAR PICO BY DANIEL MARKS CC-BY-SA 4.0

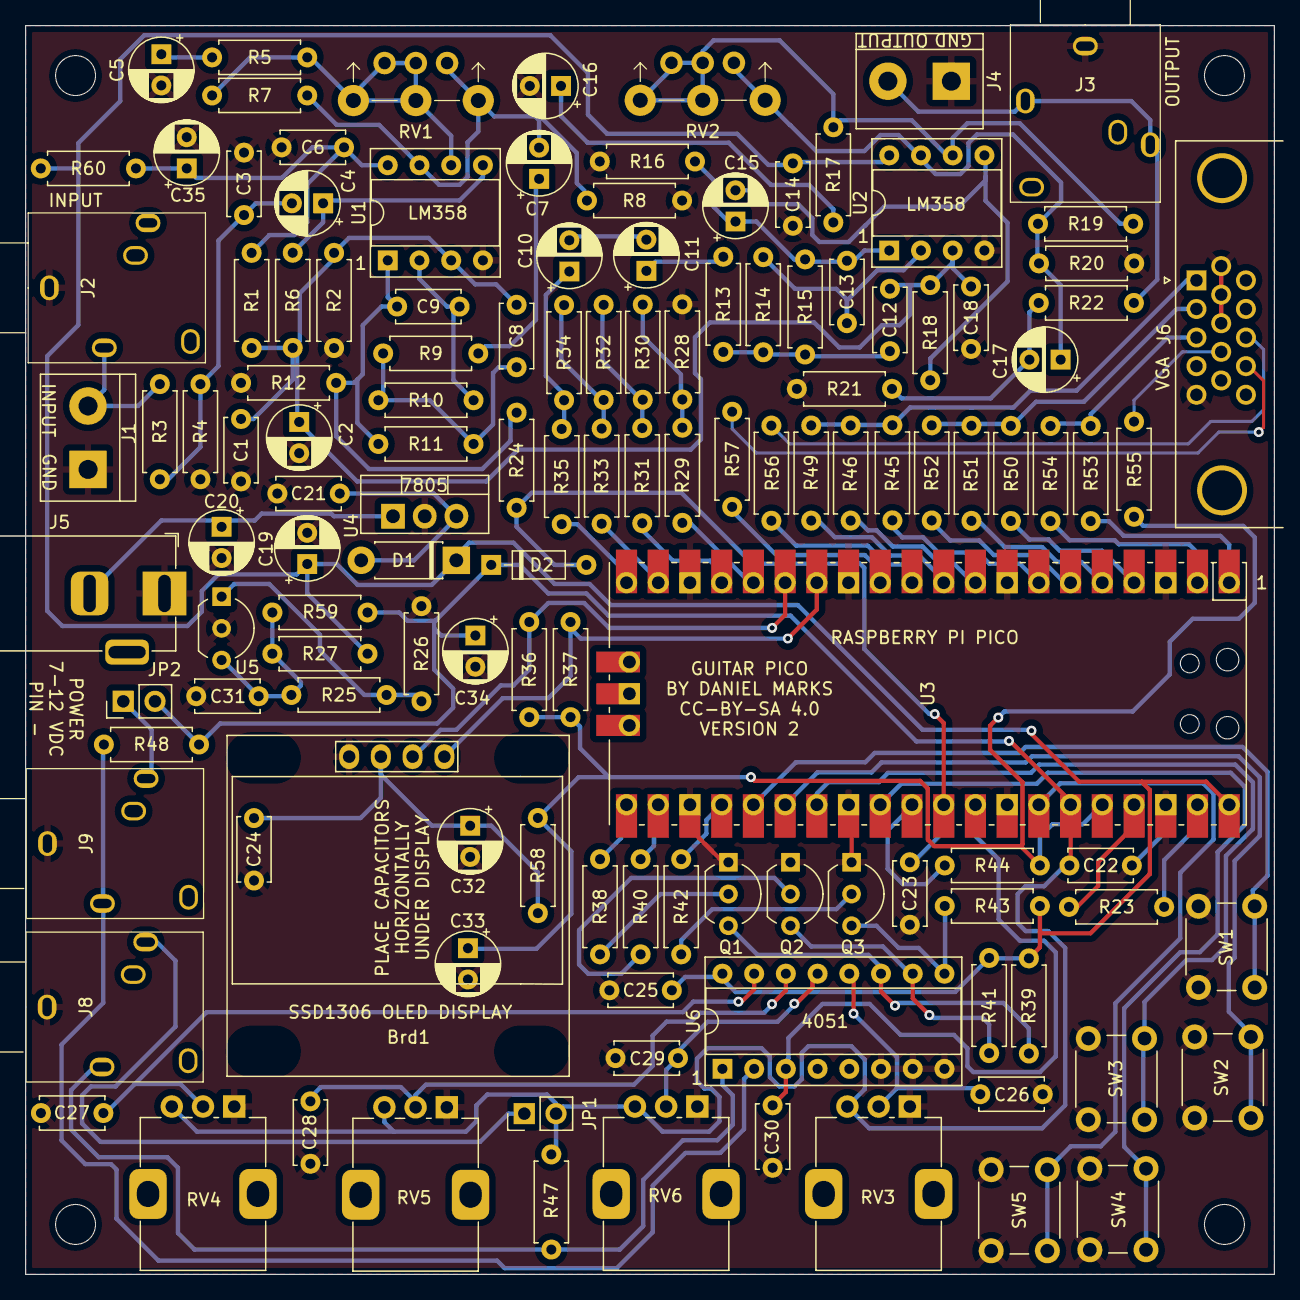
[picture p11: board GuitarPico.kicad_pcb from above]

Board: 2 copper layers, 100.0 x 100.0 mm, 132 parts (0 on the bottom side), 85 nets.

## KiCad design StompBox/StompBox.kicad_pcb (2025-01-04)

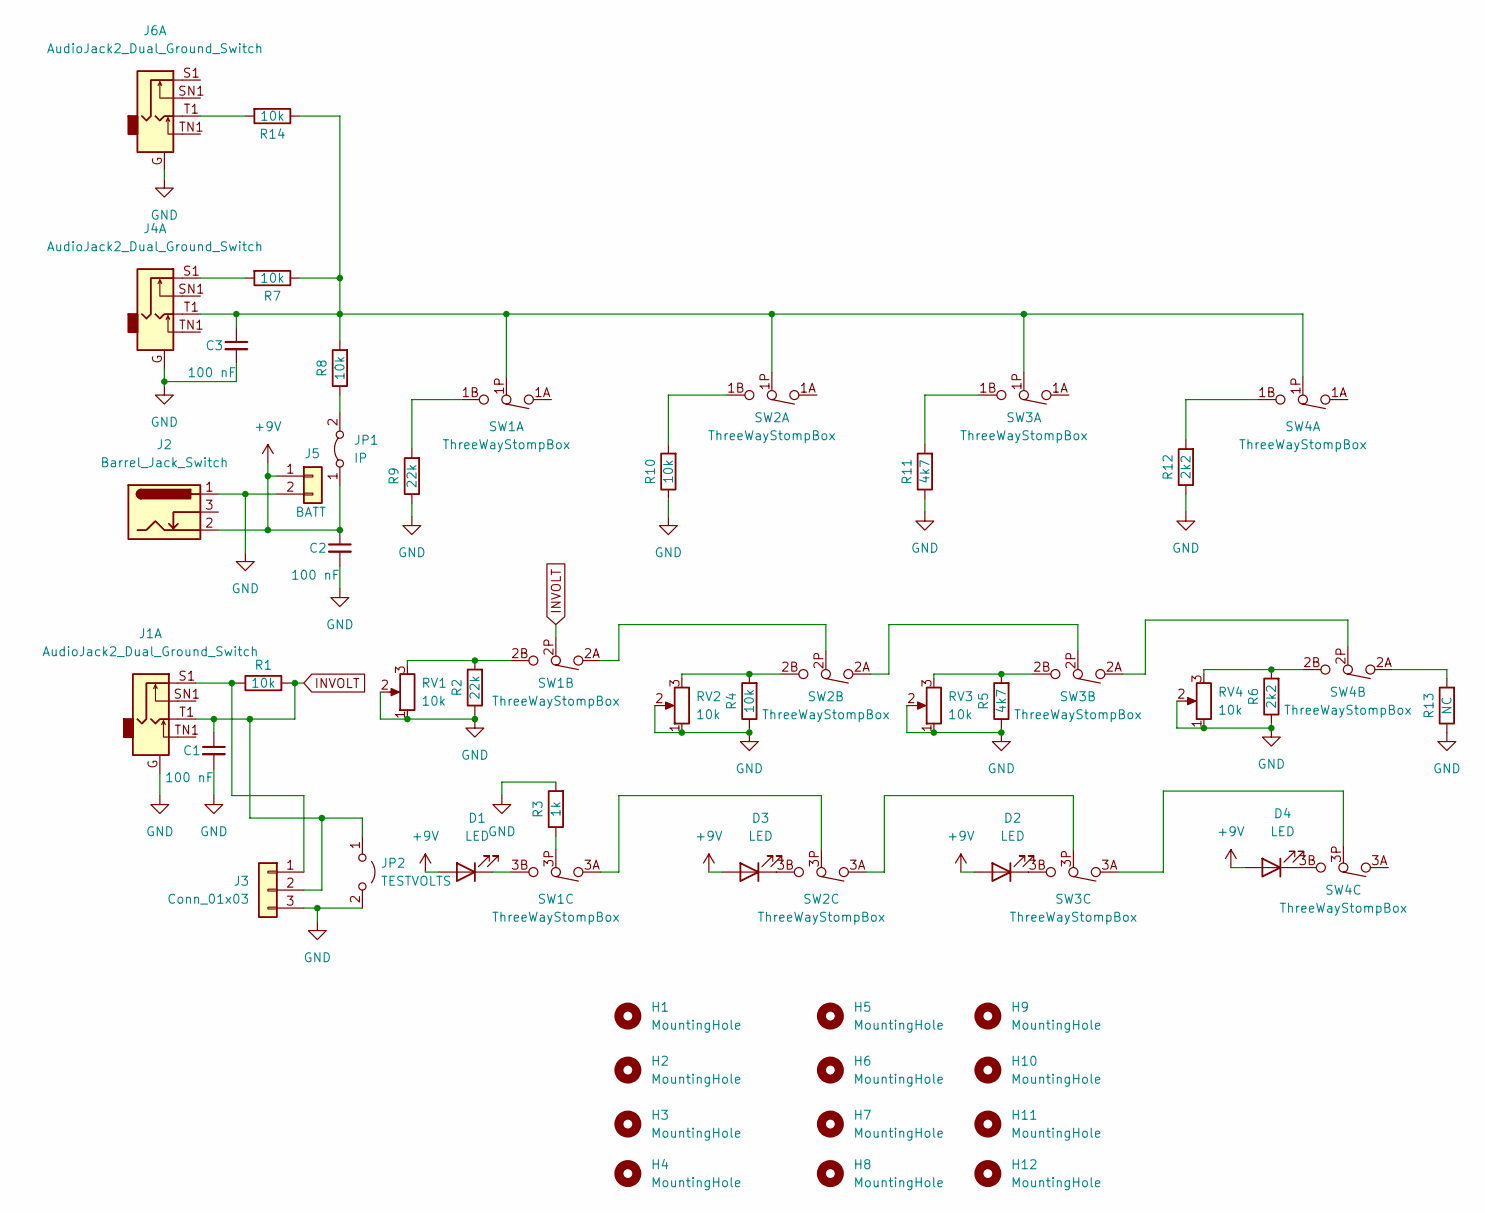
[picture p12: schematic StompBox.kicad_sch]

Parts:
C1, C2, C3: 100 nF; C_Disc_D5.0mm_W2.5mm_P5.00mm
D1, D2, D3, D4: LED; LED_D5.0mm
H1, H2, H3, H4, H5, H6, H7, H8, H9, H10, H11, H12: MountingHole; MountingHole_3.2mm_M3
J1, J4, J6: AudioJack2_Dual_Ground_Switch; PJ-3240-35mm-stereo
J2: Barrel_Jack_Switch; BarrelJack_Horizontal
J3: Conn_01x03; TerminalBlock_bornier-3_P5.08mm
J5: BATT; PinHeader_1x02_P2.54mm_Vertical
JP1: IP; PinHeader_1x02_P2.54mm_Vertical
JP2: TESTVOLTS; PinHeader_1x02_P2.54mm_Vertical
R1, R4, R7, R8, R10, R14: 10k; R_Axial_DIN0207_L6.3mm_D2.5mm_P7.62mm_Horizontal
R2, R9: 22k; R_Axial_DIN0207_L6.3mm_D2.5mm_P7.62mm_Horizontal
R3: 1k; R_Axial_DIN0207_L6.3mm_D2.5mm_P7.62mm_Horizontal
R5, R11: 4k7; R_Axial_DIN0207_L6.3mm_D2.5mm_P7.62mm_Horizontal
R6, R12: 2k2; R_Axial_DIN0207_L6.3mm_D2.5mm_P7.62mm_Horizontal
R13: NC; R_Axial_DIN0207_L6.3mm_D2.5mm_P7.62mm_Horizontal
RV1, RV2, RV3, RV4: 10k; Potentiometer_Bourns_3296W_Vertical
SW1, SW2, SW3, SW4: ThreeWayStompBox; ThreeWayStompBoxSwitch

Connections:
+9V: C2.1, D1.2 (A), D2.2 (A), D3.2 (A), D4.2 (A), J2.2, J5.1, JP1.1 (A)
GND: C1.2, C2.2, C3.2, J1.G, J2.1, J3.3, J4.G, J5.2, J6.G, JP2.2 (B), R2.1, R3.2, R4.1, R5.1, R6.1, R9.1, R10.1, R11.1, R12.1, R13.1, RV1.1, RV1.2, RV2.1, RV2.2, RV3.1, RV3.2, RV4.1, RV4.2
INVOLT: C1.1, J1.T1, J3.2, JP2.1 (A), R1.2, SW1.2P
unnamed: C3.1, J4.T1, R7.1, R8.2, R14.1, SW1.1P, SW2.1P, SW3.1P, SW4.1P
unnamed: D1.1 (K), SW1.3B
unnamed: D2.1 (K), SW3.3B
unnamed: D3.1 (K), SW2.3B
unnamed: D4.1 (K), SW4.3B
unnamed: J1.S1, J3.1, R1.1
unnamed: J4.S1, R7.2
unnamed: J6.T1, R14.2
unnamed: JP1.2 (B), R8.1
unnamed: R2.2, RV1.3, SW1.2B
unnamed: R3.1, SW1.3P
unnamed: R4.2, RV2.3, SW2.2B
unnamed: R5.2, RV3.3, SW3.2B
unnamed: R6.2, RV4.3, SW4.2B
unnamed: R9.2, SW1.1B
unnamed: R10.2, SW2.1B
unnamed: R11.2, SW3.1B
unnamed: R12.2, SW4.1B
unnamed: R13.2, SW4.2A
unnamed: SW1.2A, SW2.2P
unnamed: SW1.3A, SW2.3P
unnamed: SW2.2A, SW3.2P
unnamed: SW2.3A, SW3.3P
unnamed: SW3.2A, SW4.2P
unnamed: SW3.3A, SW4.3P

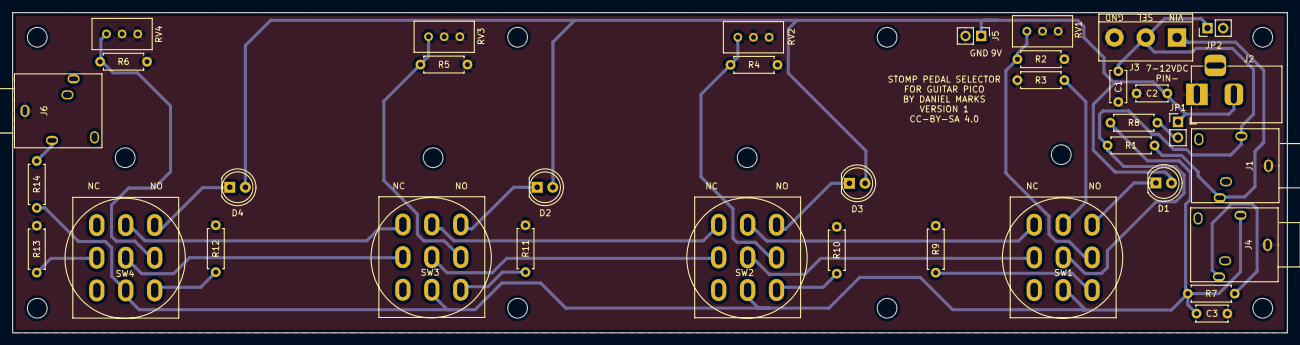
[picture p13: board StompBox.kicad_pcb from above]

Board: 2 copper layers, 207.0 x 52.0 mm, 49 parts (0 on the bottom side), 28 nets.

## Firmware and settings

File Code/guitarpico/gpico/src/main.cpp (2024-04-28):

/* main.cpp

*/

/*
   Copyright (c) 2024 Daniel Marks

  This software is provided 'as-is', without any express or implied
  warranty. In no event will the authors be held liable for any damages
  arising from the use of this software.

  Permission is granted to anyone to use this software for any purpose,
  including commercial applications, and to alter it and redistribute it
  freely, subject to the following restrictions:

  1. The origin of this software must not be misrepresented; you must not
   claim that you wrote the original software. If you use this software
   in a product, an acknowledgment in the product documentation would be
   appreciated but is not required.
  2. Altered source versions must be plainly marked as such, and must not be
   misrepresented as being the original software.
  3. This notice may not be removed or altered from any source distribution.
*/

#include "main.h"
#include "guitarpico.h"
#include "ssd1306_i2c.h"
#include "buttons.h"
#include "dsp.h"
#include "pitch.h"
#include "ui.h"
#include "tinycl.h"
#include <string.h>
#include <stdio.h>
#include <math.h>

#include "usbmain.h"

void initialize_video(void);
void halt_video(void);

#define UNCLAIMED_ALARM 0xFFFFFFFF

uint dac_pwm_b3_slice_num, dac_pwm_b2_slice_num, dac_pwm_b1_slice_num, dac_pwm_b0_slice_num;
uint claimed_alarm_num = UNCLAIMED_ALARM;

const u8* Fonts[5] = { FontBold8x8, FontGame8x8, FontIbm8x8, FontItalic8x8, FontThin8x8 };

volatile uint32_t counter = 0;

extern "C" {
    
void idle_task(void)
{
    buttons_poll();
    usb_task();
}

}

void initialize_pwm(void)
{
    gpio_set_function(DAC_PWM_B3, GPIO_FUNC_PWM);
    gpio_set_function(DAC_PWM_B2, GPIO_FUNC_PWM);
    gpio_set_function(DAC_PWM_B1, GPIO_FUNC_PWM);
    gpio_set_function(DAC_PWM_B0, GPIO_FUNC_PWM);

    dac_pwm_b3_slice_num = pwm_gpio_to_slice_num(DAC_PWM_B3);
    dac_pwm_b2_slice_num = pwm_gpio_to_slice_num(DAC_PWM_B2);
    dac_pwm_b1_slice_num = pwm_gpio_to_slice_num(DAC_PWM_B1);
    dac_pwm_b0_slice_num = pwm_gpio_to_slice_num(DAC_PWM_B0);
    
    pwm_set_clkdiv_int_frac(dac_pwm_b3_slice_num, 1, 0);
    pwm_set_clkdiv_int_frac(dac_pwm_b2_slice_num, 1, 0);
    pwm_set_clkdiv_int_frac(dac_pwm_b1_slice_num, 1, 0);
    pwm_set_clkdiv_int_frac(dac_pwm_b0_slice_num, 1, 0);
    
    pwm_set_clkdiv_mode(dac_pwm_b3_slice_num, PWM_DIV_FREE_RUNNING);
    pwm_set_clkdiv_mode(dac_pwm_b2_slice_num, PWM_DIV_FREE_RUNNING);
    pwm_set_clkdiv_mode(dac_pwm_b1_slice_num, PWM_DIV_FREE_RUNNING);
    pwm_set_clkdiv_mode(dac_pwm_b0_slice_num, PWM_DIV_FREE_RUNNING);

    pwm_set_phase_correct(dac_pwm_b3_slice_num, false);
    pwm_set_phase_correct(dac_pwm_b2_slice_num, false);
    pwm_set_phase_correct(dac_pwm_b1_slice_num, false);
    pwm_set_phase_correct(dac_pwm_b0_slice_num, false);
    
    pwm_set_wrap(dac_pwm_b3_slice_num, DAC_PWM_WRAP_VALUE-1);
    pwm_set_wrap(dac_pwm_b2_slice_num, DAC_PWM_WRAP_VALUE-1);
    pwm_set_wrap(dac_pwm_b1_slice_num, DAC_PWM_WRAP_VALUE-1);
    pwm_set_wrap(dac_pwm_b0_slice_num, DAC_PWM_WRAP_VALUE-1);
    
    pwm_set_output_polarity(dac_pwm_b3_slice_num, false, false);
    pwm_set_output_polarity(dac_pwm_b2_slice_num, false, false);
    pwm_set_output_polarity(dac_pwm_b1_slice_num, false, false);
    pwm_set_output_polarity(dac_pwm_b0_slice_num, false, false);
    
    pwm_set_enabled(dac_pwm_b3_slice_num, true);
    pwm_set_enabled(dac_pwm_b2_slice_num, true);
    pwm_set_enabled(dac_pwm_b1_slice_num, true);
    pwm_set_enabled(dac_pwm_b0_slice_num, true);
}

uint current_input;
uint control_sample_no;
uint16_t control_samples[8];

const int potvalues[6] = { 2, 1, 0, 3, 4, 6 };

uint16_t read_potentiometer_value(uint v)
{
    if ((v == 0) || (v > (sizeof(potvalues)/sizeof(potvalues[0]))))
        return 0;
    return (uint16_t)(control_samples[potvalues[v-1]]*(POT_MAX_VALUE/ADC_MAX_VALUE));
}

volatile uint32_t last1=0,last2=0,last3=0;
volatile uint32_t dly1,dly2,dly3;

volatile uint16_t next_sample = 0;

absolute_time_t last_time;

static inline absolute_time_t update_next_timeout(const absolute_time_t last_time, uint32_t us, uint32_t min_us)
{
    absolute_time_t next_time = delayed_by_us(last_time, us);
    absolute_time_t next_time_sooner = make_timeout_time_us(min_us);
    return (absolute_time_diff_us(next_time, next_time_sooner) < 0) ? next_time : next_time_sooner;
}

int32_t sample_avg;
uint32_t mag_avg;

static void __no_inline_not_in_flash_func(alarm_func)(uint alarm_num)
{
    uint16_t sample;
    uint32_t cur_time;
    absolute_time_t next_alarm_time;

    sample = adc_hw->result;
    cur_time = timer_hw->timelr;
    current_input = (current_input+1) & 0x01;
    
    adc_select_input(current_input);
    if (current_input == 0)
    {
        pwm_set_both_levels(dac_pwm_b3_slice_num, next_sample, next_sample);
        pwm_set_both_levels(dac_pwm_b1_slice_num, next_sample, next_sample);
        dly3 = cur_time-last3;
        control_samples[control_sample_no] = sample;
        control_sample_no = (control_sample_no >= 7) ? 0 : (control_sample_no+1);
        gpio_put(GPIO_ADC_SEL0, (control_sample_no & 0x01) == 0);
        gpio_put(GPIO_ADC_SEL1, (control_sample_no & 0x02) == 0);
        gpio_put(GPIO_ADC_SEL2, (control_sample_no & 0x04) == 0);
        last_time = delayed_by_us(last_time, 10);
        do
        {
            next_alarm_time = update_next_timeout(last_time, 0, 8);
        } while (hardware_alarm_set_target(claimed_alarm_num, next_alarm_time));
        last2 = cur_time;
        return;
    } 

    dly1 = cur_time-last1;
    last1 = cur_time;
    last3 = cur_time;
    dly2 = cur_time-last2;

    int16_t s = (sample - (ADC_MAX_VALUE/2))*(ADC_PREC_VALUE/ADC_MAX_VALUE);
    sample_avg = (sample_avg*511)/512 + s;
    s -= (sample_avg / 512);
    if (s < (-ADC_PREC_VALUE/2)) s = (-ADC_PREC_VALUE/2);
    if (s > (ADC_PREC_VALUE/2-1)) s = (ADC_PREC_VALUE/2-1);
    mag_avg = (mag_avg*511)/512 + ((uint32_t)abs(s));
    if (mag_avg < (512*ADC_PREC_VALUE/512))
        pitch_current_entry = 0;
    insert_pitch_edge(s, counter);
    insert_sample_circ_buf_clean(s);
    s = dsp_process_all_units(s);
    insert_sample_circ_buf(s);
    if (s > (ADC_PREC_VALUE/2-1)) next_sample = DAC_PWM_WRAP_VALUE-1;
    else if (s < (-ADC_PREC_VALUE/2)) next_sample = 0;
    else next_sample = (s+(ADC_PREC_VALUE/2)) / (ADC_PREC_VALUE/DAC_PWM_WRAP_VALUE);
    last_time = delayed_by_us(last_time, 30);
    do
    {
        next_alarm_time = update_next_timeout(last_time, 0, 8);
    } while (hardware_alarm_set_target(claimed_alarm_num, next_alarm_time));
    counter++;
}

void reset_periodic_alarm(void)
{
    if (claimed_alarm_num == UNCLAIMED_ALARM) return;
    
    hardware_alarm_cancel(claimed_alarm_num);
    control_sample_no = 0;
    current_input = 0;
    hardware_alarm_set_callback(claimed_alarm_num, alarm_func);
    last_time = make_timeout_time_us(1000);
    absolute_time_t next_alarm_time = update_next_timeout(last_time, 0, 8);
    //absolute_time_t next_alarm_time = make_timeout_time_us(1000);
    hardware_alarm_set_target(claimed_alarm_num, next_alarm_time);
}


void initialize_periodic_alarm(void)
{
    if (claimed_alarm_num != UNCLAIMED_ALARM)
    {
        reset_periodic_alarm();
        return;
    }
    claimed_alarm_num = hardware_alarm_claim_unused(true);
    reset_periodic_alarm();
    /*for (uint alarm_no=0;alarm_no<4;alarm_no++)
    {
        if (!hardware_alarm_is_claimed(alarm_no))
        {
            hardware_alarm_claim_unused(alarm_no);
            claimed_alarm_num = alarm_no;
            reset_periodic_alarm();
            break;
        }
    } */
}

void initialize_adc(void)
{
    
    adc_init();
    adc_gpio_init(ADC_AUDIO_IN);
    adc_gpio_init(ADC_CONTROL_IN);
    adc_set_clkdiv(100);
    adc_set_round_robin(0);
    adc_run(false);
    adc_select_input(0);
    current_input = 0;
    adc_run(true);
}

void initialize_gpio(void)
{
    // initialize debug LED
    gpio_init(LED_PIN);
    gpio_set_dir(LED_PIN, GPIO_OUT);

    gpio_init(GPIO_ADC_SEL0);
    gpio_set_dir(GPIO_ADC_SEL0, GPIO_OUT);
    gpio_init(GPIO_ADC_SEL1);
    gpio_set_dir(GPIO_ADC_SEL1, GPIO_OUT);
    gpio_init(GPIO_ADC_SEL2);
    gpio_set_dir(GPIO_ADC_SEL2, GPIO_OUT);

    gpio_init(23);
    gpio_set_dir(23, GPIO_OUT);
    gpio_put(23, 1);
}

char buttonpressed(uint8_t b)
{
    return button_readbutton(b) ? '1' : '0';
}

void adjust_parms(uint8_t unit_no)
{
    int sel = 0, redraw = 1;
    button_clear();
    for (;;)
    {
        const dsp_parm_configuration_entry *d = dpce[dsp_parms[unit_no].dtn.dut];
        idle_task();
        if (redraw)
        {
            if (sel == 0)
            {
                write_str_with_spaces(0,2,"Type",16);
                write_str_with_spaces(0,3,dtnames[dsp_parms[unit_no].dtn.dut],16);
            } else
            {
                char s[20];
                write_str_with_spaces(0,2,d[sel-1].desc,16);
                char *c = number_str(s, 
                    dsp_read_value_prec((void *)(((uint8_t *)&dsp_parms[unit_no]) + d[sel-1].offset), d[sel-1].size), 
                    d[sel-1].digits, 0);
                write_str_with_spaces(0,3,c,16);
            }
            display_refresh();
            redraw = 0;            
        }
        if (button_left())
        {
            button_clear();
            break;
        }
        else if (button_down() && (sel > 0))
        {
            sel--;
            redraw = 1;
        } else if (button_up())
        {
            if (d[sel].desc != NULL)
            {
                sel++;
                redraw = 1;
            }
        } else if (button_right() || button_enter())
        {
            if (sel == 0)
            {
                write_str_with_spaces(0,2,"Type select",16);
                menu_str mst = { dtnames,0,3,10,0,0 };
                mst.item = mst.itemesc = dsp_parms[unit_no].dtn.dut;
                int res;
                do_show_menu_item(&mst);
                do
                {
                    idle_task();
                    res = do_menu(&mst);
                } while (res == 0);
                if (res == 3)
                {
                    if (mst.item != dsp_parms[unit_no].dtn.dut)
                    {
                        dsp_unit_initialize(unit_no, (dsp_unit_type)mst.item);
                        dsp_unit_reset_all();
                    }
                }
            } else
            {
                scroll_number_dat snd = { 0, 3, 
                                          d[sel-1].digits,
                                          0,
                                          d[sel-1].minval,
                                          d[sel-1].maxval,
                                          0,
                                          dsp_read_value_prec((void *)(((uint8_t *)&dsp_parms[unit_no]) + d[sel-1].offset), d[sel-1].size),
                                          0, 0 };
                scroll_number_start(&snd);
                do
                {
                    idle_task();
                    scroll_number_key(&snd);
                } while (!snd.entered);
                if (snd.changed)
                   dsp_set_value_prec((void *)(((uint8_t *)&dsp_parms[unit_no]) + d[sel-1].offset), d[sel-1].size, snd.n);
            }
            redraw = 1;
        }
    }
    
    
}

void adjust_dsp_params(void)
{
    int unit_no = 0, redraw = 1;
    char s[20];

    button_clear();
    for (;;)
    {
        idle_task();
        if (redraw)
        {
            clear_display();
            write_str(0,0,"DSP Adj");
            sprintf(s,"Unit #%d", unit_no+1);
            write_str_with_spaces(0,1,s,16);
            write_str_with_spaces(0,2,dtnames[dsp_parms[unit_no].dtn.dut],16);
            display_refresh();
            redraw = 0;
        }
        if (button_left())
        {
            button_clear();
            break;
        }
        else if (button_down() && (unit_no > 0))
        {
            unit_no--;
            redraw = 1;
        } else if (button_up() && (unit_no < (MAX_DSP_UNITS-1)))
        {
            unit_no++;
            redraw = 1;
        } else if (button_right() || button_enter())
        {
           sprintf(s,"Unit #%d select", unit_no+1);
           write_str_with_spaces(0,1,s,16);
           adjust_parms(unit_no);
           redraw = 1;
        }
    }
}

int main2();

#define FLASH_BANKS 10
#define FLASH_PAGE_BYTES 4096u
#define FLASH_OFFSET_STORED (2*1024*1024)
#define FLASH_BASE_ADR 0x10000000
#define FLASH_MAGIC_NUMBER 0xFEE1FEDE

#define FLASH_PAGES(x) ((((x)+(FLASH_PAGE_BYTES-1))/FLASH_PAGE_BYTES)*FLASH_PAGE_BYTES)

uint32_t last_gen_no;
uint8_t  desc[16];
uint32_t pedal_onoff = 0;
uint8_t  pedal_control[4] = { 1, 2, 3, 4 };

typedef struct _flash_layout_data
{
    uint32_t magic_number;
    uint32_t gen_no;
    uint8_t  desc[16];
    dsp_parm dsp_parms[MAX_DSP_UNITS];
} flash_layout_data;

typedef union _flash_layout
{ 
    flash_layout_data fld;
    uint8_t      space[FLASH_PAGE_BYTES];
} flash_layout;

inline static uint32_t flash_offset_bank(uint bankno)
{
    return (FLASH_OFFSET_STORED - FLASH_PAGES(sizeof(flash_layout)) * (bankno+1));
}

inline static const uint8_t *flash_offset_address_bank(uint bankno)
{
    const uint8_t *const flashadr = (const uint8_t *const) FLASH_BASE_ADR;
    return &flashadr[flash_offset_bank(bankno)];
}

void message_to_display(const char *msg)
{
    write_str_with_spaces(0,5,msg,16);
    display_refresh();

    buttons_clear();
    for (;;)
    {
       idle_task();
       if (button_enter()) break;
     }
}
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
int main()
{
    usb_init();    
    //stdio_init_all();
    initialize_dsp();
    initialize_pitch();
    initialize_gpio();
    buttons_initialize();
    initialize_pwm();
    ssd1306_Initialize();
    initialize_video();
    initialize_adc();
    initialize_periodic_alarm();
    flash_load_most_recent();
    
    for (;;)
    {
        clear_display();
        write_str(0,0,"GuitarPico");
        write_str_with_spaces(0,1,(char *)desc,15);
        pedal_display_state();
        do_show_menu_item(&mainmenu_str);
        buttons_clear();
        for (;;)
        {
            if (tinycl_task(sizeof(tcmds) / sizeof(tinycl_command), tcmds, NULL))
            {
                tinycl_do_echo = 1;
                tinycl_put_string("> ");
            }
            pedal_switch();
            idle_task();
            uint val = do_menu(&mainmenu_str);
            if ((val == 2) || (val == 3)) break;
        }
        switch (mainmenu_str.item)
        {
            case 0:  adjust_dsp_params();
                     break;
            case 1:  pitch_measure();
                     break;
            case 2:  debugstuff();
                     break;
            case 3:  pedal_control_cmd();
                     break;
            case 4:  flash_load();
                     break;
            case 5:  flash_save();
                     break;
        }
    }
}


// Draw box
#if FORMAT==CANVAS_PLANE2
u8 Box[2*WIDTHBYTE*HEIGHT] __attribute__ ((aligned(4)));
#elif FORMAT==CANVAS_ATTRIB8
u8 Box[WIDTHBYTE*HEIGHT + WIDTHBYTE*((HEIGHT+7)/8)] __attribute__ ((aligned(4)));
#else
u8 Box[WIDTHBYTE*HEIGHT] __attribute__ ((aligned(4)));
#endif
//sCanvas Canvas; // canvas of draw box

// image (RPi)
u8 Img[1280] __attribute__ ((aligned(4)));
sCanvas ImgCanvas; // canvas of image

// image (Peter)
u8 Img2[1024] __attribute__ ((aligned(4)));
sCanvas Img2Canvas; // canvas of image

// 16-color palette translation table
//u16 Pal16Trans[256];

// 4-color palette translation table
u32 Pal4Trans[256];

// initialize videomode
void VideoInit()
{
    // setup videomode
    VgaCfgDef(&Cfg); // get default configuration
    Cfg.video = &DRV; // video timings
    Cfg.width = WIDTH; // screen width
    Cfg.height = HEIGHT; // screen height
#ifdef DOUBLEY
    Cfg.dbly = true;
#endif
    VgaCfg(&Cfg, &Vmode); // calculate videomode setup

    // initialize base layer 0
    ScreenClear(pScreen);
    sStrip* t = ScreenAddStrip(pScreen, HEIGHT);

    // draw box
    sSegm* g = ScreenAddSegm(t, WIDTH);

#if FORMAT==CANVAS_8
    ScreenSegmGraph8(g, Box, WIDTHBYTE);
    memcpy(Img, RPi8Img, sizeof(RPi8Img));
    memcpy(Img2, Peter8Img, sizeof(Peter8Img));

#elif FORMAT==CANVAS_4
    GenPal16Trans(Pal16Trans, DefPal16); // generate palette translation table
    ScreenSegmGraph4(g, Box, Pal16Trans, WIDTHBYTE);

    memcpy(Img, RPi4Img, sizeof(RPi4Img));
    memcpy(Img2, Peter4Img, sizeof(Peter4Img));

#elif FORMAT==CANVAS_2
    GenPal4Trans(Pal4Trans, PalCGA6); // generate palette translation table
    ScreenSegmGraph2(g, Box, Pal4Trans, WIDTHBYTE);

    memcpy(Img, RPi2Img, sizeof(RPi2Img));
    memcpy(Img2, Peter2Img, sizeof(Peter2Img));

#elif FORMAT==CANVAS_1
    ScreenSegmGraph1(g, Box, COL_BLACK, COL_WHITE, WIDTHBYTE);

    memcpy(Img, RPi1Img, sizeof(RPi1Img));
    ImgInvert(Img, sizeof(RPi1Img));
    memcpy(Img2, Peter1Img, sizeof(Peter1Img));
    ImgInvert(Img2, sizeof(Peter1Img));

#elif FORMAT==CANVAS_PLANE2
    GenPal4Plane(Pal4Trans, PalCGA2); // generate palette translation table
    ScreenSegmPlane2(g, Box, WIDTHBYTE*HEIGHT, Pal4Trans, WIDTHBYTE);
    Canvas.img2 = &Box[WIDTHBYTE*HEIGHT];

    ImgCanvas.img2 = &Img[IMGWIDTHBYTE*IMGHEIGHT];
    Plane2Conv(Img, ImgCanvas.img2, RPi2Img, IMGWIDTH, IMGHEIGHT);

    Img2Canvas.img2 = &Img2[IMG2WIDTHBYTE*IMG2HEIGHT];
    Plane2Conv(Img2, Img2Canvas.img2, Peter2Img, IMG2WIDTH, IMG2HEIGHT);

#elif FORMAT==CANVAS_ATTRIB8
    ScreenSegmAttrib8(g, Box, &Box[WIDTHBYTE*HEIGHT], DefPal16, WIDTHBYTE);
    Canvas.img2 = &Box[WIDTHBYTE*HEIGHT];

    ImgCanvas.img2 = &Img[IMGWIDTHBYTE*IMGHEIGHT];
    Attr8Conv(Img, ImgCanvas.img2, RPi4Img, IMGWIDTH, IMGHEIGHT, DefPal16);

    Img2Canvas.img2 = &Img2[IMG2WIDTHBYTE*IMG2HEIGHT];
    Attr8Conv(Img2, Img2Canvas.img2, Peter4Img, IMG2WIDTH, IMG2HEIGHT, DefPal16);
#endif

    // canvas of draw box
    Canvas.img = Box;
    Canvas.w = WIDTH;
    Canvas.h = HEIGHT;
    Canvas.wb = WIDTHBYTE;
    Canvas.format = FORMAT;

    // canvas of image
    ImgCanvas.img = Img;
    ImgCanvas.w = IMGWIDTH;
    ImgCanvas.h = IMGHEIGHT;
    ImgCanvas.wb = IMGWIDTHBYTE;
    ImgCanvas.format = FORMAT;

    // canvas of image 2
    Img2Canvas.img = Img2;
    Img2Canvas.w = IMG2WIDTH;
    Img2Canvas.h = IMG2HEIGHT;
    Img2Canvas.wb = IMG2WIDTHBYTE;
    Img2Canvas.format = FORMAT;

    // initialize system clock
    set_sys_clock_pll(Vmode.vco*1000, Vmode.pd1, Vmode.pd2);

    // initialize videomode
    VgaInitReq(&Vmode);

}

void initialize_video(void)
{
    // run VGA core
    StartVgaCore();

    // initialize videomode
    VideoInit();
}

void halt_video(void)
{
    VgaInitReq(NULL);
}

int main2()
{
    Bool slow = True;
    u32 t, t2;

    initialize_video();

    // initialize debug LED
    gpio_init(LED_PIN);
    gpio_set_dir(LED_PIN, GPIO_OUT);

    // main loop
    t = time_us_32();
    while (true)
    {
        switch (RandU8Max(7))
        {
        case 0:
            DrawRect(&Canvas, RandS16MinMax(-50, WIDTH), RandS16MinMax(-50, HEIGHT),
                RandU16MinMax(1, 100), RandU16MinMax(1, 100), RandU8Max(MAXCOL));
            break;

        case 1:
            DrawFrame(&Canvas, RandS16MinMax(-50, WIDTH), RandS16MinMax(-50, HEIGHT),
                RandU16MinMax(4, 100), RandU16MinMax(4, 100), RandU8Max(MAXCOL));
            break;

        case 2:
            DrawPoint(&Canvas, RandS16MinMax(-50, WIDTH+50), RandS16MinMax(-50, HEIGHT+50), RandU8Max(MAXCOL));
            break;

        case 3:
            DrawLine(&Canvas, RandS16MinMax(-50, WIDTH+50), RandS16MinMax(-50, HEIGHT+50),
                RandS16MinMax(-50, WIDTH+50), RandS16MinMax(-50, HEIGHT+50), RandU8Max(MAXCOL));
            break;

        case 4:
            DrawFillCircle(&Canvas, RandS16MinMax(-50, WIDTH+50), RandS16MinMax(-50, HEIGHT+50),
                RandU16MinMax(1, 50), RandU8Max(MAXCOL), RandU8());
            break;

        case 5:
            DrawCircle(&Canvas, RandS16MinMax(-50, WIDTH+50), RandS16MinMax(-50, HEIGHT+50),
                RandU16MinMax(1, 50), RandU8Max(MAXCOL), RandU8());
            break;

        case 6:
            DrawText(&Canvas, "Hello!", RandS16MinMax(-50, WIDTH+50), RandS16MinMax(-50, HEIGHT+50), RandU8Max(MAXCOL),
                Fonts[RandU8Max(4)], 8, RandS8MinMax(1,4), RandS8MinMax(1,4));
            break;

        case 7:
            if (RandU8Max(1)==0)
            {
#if FORMAT == CANVAS_ATTRIB8 
                DrawImg(&Canvas, &Img2Canvas, RandS16MinMax(-50, WIDTH-10) & ~7, RandS16MinMax(-50, HEIGHT-10) & ~7,
                    0, 0, IMG2WIDTH, IMG2HEIGHT);
#else
                DrawImg(&Canvas, &Img2Canvas, RandS16MinMax(-50, WIDTH-10), RandS16MinMax(-50, HEIGHT-10),
                    0, 0, IMG2WIDTH, IMG2HEIGHT);
#endif
            }
            else
            {
#if FORMAT == CANVAS_ATTRIB8 
                DrawBlit(&Canvas, &ImgCanvas, RandS16MinMax(-50, WIDTH-10) & ~7, RandS16MinMax(-50, HEIGHT-10) & ~7,
                    0, 0, IMGWIDTH, IMGHEIGHT, MAXCOL);
#else
                DrawBlit(&Canvas, &ImgCanvas, RandS16MinMax(-50, WIDTH-10), RandS16MinMax(-50, HEIGHT-10),
                    0, 0, IMGWIDTH, IMGHEIGHT, MAXCOL);
#endif
            }
            break;
        }

        // change mode after some time
        t2 = time_us_32();
        if (slow)
        {
            if ((t2 - t) > 8000000)
            {
                slow = False;
                t = t2;
            }
            sleep_ms(50);
        }
        else
        {
            if ((t2 - t) > 2000000)
            {
                slow = True;
                t = t2;
            }
        }
        gpio_put(LED_PIN, slow);
    }
}

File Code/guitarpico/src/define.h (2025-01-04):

/** 
 * @file 
 * @brief VGA common definitions of C and ASM
 * @author Miroslav Nemecek <Panda38@seznam.cz>
*/

#include "vga_config.h"		// VGA configuration

#define LAYERS_MAX	4	// max. number of layers (should be 4)

#define BLACK_MAX	MAXX	// size of buffer with black color (used to clear rest of unused line)

/// @addtogroup LayersGroup
/// @{

// VGA PIO program
#define BASE_OFFSET	17		///< Offset of base layer PIO program
#define LAYER_OFFSET	0	///< Offset of overlapped layer PIO program

// layer program
#define LAYERPROG_BASE	0	///< Program of base layer (overlapped layers are OFF)
#define LAYERPROG_KEY	1	///< Layer with key color
#define LAYERPROG_BLACK	2	///< Layer with black key color
#define LAYERPROG_WHITE	3	///< Layer with white key color
#define LAYERPROG_MONO	4	///< Layer with mono pattern or simple color
#define LAYERPROG_RLE	5	///< Layer with RLE compression

#define LAYERPROG_NUM	6	///< Number of layer programs

// layer mode (CPP = clock cycles per pixel)
//	Control buffer: 16 bytes
//	Data buffer: 4 bytes
// fast sprites can be up Control buffer: width*2 bytes
// sprites Data buffer: width bytes
#define LAYERMODE_BASE		0			///< Base layer
#define LAYERMODE_KEY		1			///< Layer with key color
#define LAYERMODE_BLACK		2			///< layer with black key color
#define LAYERMODE_WHITE		3			///< Layer with white key color
#define LAYERMODE_MONO		4			///< Layer with mono pattern
#define LAYERMODE_COLOR		5			///< layer with simple color
#define LAYERMODE_RLE		6			///< Layer with RLE compression
#define LAYERMODE_SPRITEKEY	7			///< Layer with sprites with key color
#define LAYERMODE_SPRITEBLACK	8		///< Layer with sprites with black key color
#define LAYERMODE_SPRITEWHITE	9		///< Layer with sprites with white key color
#define LAYERMODE_FASTSPRITEKEY	10		///< Layer with fast sprites with key color
#define LAYERMODE_FASTSPRITEBLACK 11	///< Layer with fast sprites with black key color
#define LAYERMODE_FASTSPRITEWHITE 12	///< Layer with fast sprites with white key color
#define LAYERMODE_PERSPKEY		13		///< Layer with key color and image with transformation matrix
#define LAYERMODE_PERSPBLACK	14		///< Layer with black key color and image with transformation matrix
#define LAYERMODE_PERSPWHITE	15		///< Layer with white key color and image with transformation matrix
#define LAYERMODE_PERSP2KEY		16		///< Layer with key color and double-pixel image with transformation matrix
#define LAYERMODE_PERSP2BLACK	17		///< Layer with black key color and double-pixel image with transformation matrix
#define LAYERMODE_PERSP2WHITE	18		///< Layer with white key color and double-pixel image with transformation matrix

#define LAYERMODE_NUM	19				///< Number of overlapped layer modes

/// @}

// Structure of sprite sSprite (on change update structure sSprite in vga_layer.h)
#define SSPRITE_IMG	0	// u8*	img;	// pointer to image data
#define SSPRITE_X0	4	// u8*	x0;	// pointer to pixel offset of start of lines/4 (used with fast sprites)
#define SSPRITE_W0	8	// u8*	w0;	// pointer to pixel length of length of lines/4 (used with fast sprites)
#define SSPRITE_KEYCOL	12	// u32	keycol;	// key color
#define SSPRITE_X	16	// s16	x;	// sprite X-coordinate on the screen
#define SSPRITE_Y	18	// s16	y;	// sprite Y-coordinate on the screen
#define SSPRITE_W	20	// u16	w;	// sprite width
#define SSPRITE_H	22	// u16	h;	// sprite height
#define SSPRITE_WB	24	// u16	wb;	// sprite pitch (number of bytes between lines)
				// u16	res;	// ...reserved, structure align
#define	SSPRITE_SIZE	28	// size of sSprite structure

// Structure of layer screen sLayer (on change update structure sLayer in vga_layer.h)
#define SLAYER_IMG	0	// const u8*	img;	// pointer to image in current layer format, or sprite list
#define SLAYER_PAR	4	// const void* par;	// additional parameter (RLE index table, transformation matrix)
#define SLAYER_INIT	8	// u32 	init;	// init word sent on start of scanline
#define SLAYER_KEYCOL	12	// u32	keycol;	// key color
#define SLAYER_TRANS	16	// u16	trans;	// trans count
#define SLAYER_X	18	// s16	x;	// start X coordinate
#define SLAYER_Y	20	// s16	y;	// start Y coordinate
#define SLAYER_W	22	// u16	w;	// width in pixels
#define SLAYER_H	24	// u16	h;	// height
#define SLAYER_WB	26	// u16	wb;	// image width in bytes (pitch of lines)
#define SLAYER_MODE	28	// u8	mode;	// layer mode
#define SLAYER_HORIZ	29	// s8	horiz;	// horizon of perspective projection/4 (only with LAYERMODE_PERSP* modes, 0=no perspecitve, <0 ceilling)
#define SLAYER_XBITS	30	// u8	xbits;	// number of bits of width of source image (only with LAYERMODE_PERSP* modes)
#define SLAYER_YBITS	31	// u8	ybits;	// number of bits of height of source image (only with LAYERMODE_PERSP* modes)
#define SLAYER_SPRITENUM 32	// u16	spritenum; // number of sprites
#define SLAYER_ON	34	// Bool on;	// layer is ON
#define SLAYER_CPP	35	// u8	cpp;	// current clock pulses per pixel (used to calculate X coordinate)
#define SLAYER_SIZE	36	// size of sLayer structure
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

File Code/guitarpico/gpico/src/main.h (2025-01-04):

/* main.h

*/

/*
   Copyright (c) 2024 Daniel Marks

  This software is provided 'as-is', without any express or implied
  warranty. In no event will the authors be held liable for any damages
  arising from the use of this software.

  Permission is granted to anyone to use this software for any purpose,
  including commercial applications, and to alter it and redistribute it
  freely, subject to the following restrictions:

  1. The origin of this software must not be misrepresented; you must not
   claim that you wrote the original software. If you use this software
   in a product, an acknowledgment in the product documentation would be
   appreciated but is not required.
  2. Altered source versions must be plainly marked as such, and must not be
   misrepresented as being the original software.
  3. This notice may not be removed or altered from any source distribution.
*/

#ifndef _MAIN_H
#define _MAIN_H

#include "picovga.h"

// used canvas format
#define FORMAT CANVAS_8		// 8-bit pixels
//#define FORMAT CANVAS_4	// 4-bit pixels
//#define FORMAT CANVAS_2	// 2-bit pixels
//#define FORMAT CANVAS_1	// 1-bit pixels
//#define FORMAT CANVAS_PLANE2	// 4 colors on 2 planes
//#define FORMAT CANVAS_ATTRIB8	// 2x4 bit color attributes per 8x8 pixel sample

// screen resolution
#if FORMAT==CANVAS_8
#define WIDTH	320	// screen width
#define HEIGHT	240	// screen height
#define DOUBLEY
#define DRV	VideoEGA // driver
#else
#define WIDTH	640	// screen width
#define HEIGHT	480	// screen height
#define DRV	VideoVGA // driver
#endif

#if FORMAT==CANVAS_8
#define WIDTHBYTE WIDTH		// bytes per line
#define MAXCOL	0xff		// max color

#elif FORMAT==CANVAS_4
#define WIDTHBYTE (WIDTH/2)	// bytes per line
#define MAXCOL	0x0f		// max color

#elif FORMAT==CANVAS_2
#define WIDTHBYTE (WIDTH/4)	// bytes per line
#define MAXCOL	0x03		// max color

#elif FORMAT==CANVAS_1
#define WIDTHBYTE (WIDTH/8)	// bytes per line
#define MAXCOL	0x01		// max color

#elif FORMAT==CANVAS_PLANE2
#define WIDTHBYTE (WIDTH/8)	// bytes per line
#define MAXCOL	0x03		// max color

#elif FORMAT==CANVAS_ATTRIB8
#define WIDTHBYTE (WIDTH/8)	// bytes per line
#define MAXCOL	0x1f		// max color
#endif

#define IMGWIDTH 32		// image width (RPi)
#define IMGHEIGHT 40		// image height
#define IMGWIDTHBYTE (IMGWIDTH/(WIDTH/WIDTHBYTE)) // bytes per line of image

#define IMG2WIDTH 32		// image 2 width (Peter)
#define IMG2HEIGHT 32		// image 2 height
#define IMG2WIDTHBYTE (IMG2WIDTH/(WIDTH/WIDTHBYTE)) // bytes per line of image 2

// format: 1-bit pixel graphics
// image width: 32 pixels
// image height: 40 lines
// image pitch: 4 bytes
extern const u8 RPi1Img[160] __attribute__ ((aligned(4)));

// format: 2-bit pixel graphics
// image width: 32 pixels
// image height: 40 lines
// image pitch: 8 bytes
extern const u8 RPi2Img[320] __attribute__ ((aligned(4)));

// format: 4-bit pixel graphics
// image width: 32 pixels
// image height: 40 lines
// image pitch: 16 bytes
extern const u8 RPi4Img[640] __attribute__ ((aligned(4)));

// format: 8-bit pixel graphics
// image width: 32 pixels
// image height: 40 lines
// image pitch: 32 bytes
extern const u8 RPi8Img[1280] __attribute__ ((aligned(4)));

// format: 1-bit pixel graphics
// image width: 32 pixels
// image height: 32 lines
// image pitch: 4 bytes
extern const u8 Peter1Img[128] __attribute__ ((aligned(4)));

// format: 2-bit pixel graphics
// image width: 32 pixels
// image height: 32 lines
// image pitch: 8 bytes
extern const u8 Peter2Img[256] __attribute__ ((aligned(4)));

// format: 4-bit pixel graphics
// image width: 32 pixels
// image height: 32 lines
// image pitch: 16 bytes
extern const u8 Peter4Img[512] __attribute__ ((aligned(4)));

// format: 8-bit pixel graphics
// image width: 32 pixels
// image height: 32 lines
// image pitch: 32 bytes
extern const u8 Peter8Img[1024] __attribute__ ((aligned(4)));


#endif // _MAIN_H

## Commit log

2023-09-02 Before replacing with buttons
    [GuitarPico.kicad_pcb, GuitarPico.kicad_sch]
2023-09-02 replaced with buttons
    [GuitarPico-B_Cu.gbr, GuitarPico-B_Mask.gbr, GuitarPico-B_Paste.gbr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]
2023-09-02 Fixed TL431 wiring problem
    [GuitarPico-B_Cu.gbr, GuitarPico-B_Mask.gbr, GuitarPico-B_Paste.gbr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]
2023-09-02 Added VGA connector!
    [GuitarPico.kicad_pcb, GuitarPico.kicad_sch]
2023-09-03 Flipped resistor
    [GuitarPico-B_Cu.gbr, GuitarPico-B_Mask.gbr, GuitarPico-B_Paste.gbr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]
2023-09-15 Added CAD pedal
    [GuitarPedal-BottomPedal.stl, GuitarPedal-PivotRodLeft.stl, GuitarPedal-PivotRodRight.stl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]
2023-09-17 Adjusted dimensions
    [GuitarPedal-BottomPedal.stl, GuitarPedal-PivotRodLeft.stl, GuitarPedal-PivotRodRight.stl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]
2023-09-17 Added simulations
    [Filter.sch, Filter2.sch, Filter3.sch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]
2023-12-11 Added FIR Filter examples
    [GuitarPedal-BottomPedal.stl, GuitarPedal-PivotRodLeft.stl, GuitarPedal-PivotRodRight.stl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]
2023-12-25 First example of guitarpico project
    [GuitarPico.kicad_pcb, GuitarPico.kicad_sch]
2023-12-27 Working pass thru
    [Filter2.sch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]
2023-12-28 Added ui elements
    [GuitarPico-B_Cu.gbr, GuitarPico-B_Mask.gbr, GuitarPico-B_Paste.gbr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]
2023-12-30 can now edit parameters
    [GuitarPico-B_Cu.gbr, GuitarPico-B_Mask.gbr, GuitarPico-B_Paste.gbr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]
2023-12-31 Working IIR filters
2024-01-03 Added room guitar effect
    [GuitarPico-B_Cu.gbr, GuitarPico-B_Mask.gbr, GuitarPico-B_Paste.gbr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]
2024-01-13 Try phaser again
    [GuitarPico-B_Cu.gbr, GuitarPico-B_Mask.gbr, GuitarPico-B_Paste.gbr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]
2024-01-16 Added primitive pitch shift
2024-01-16 Much improved pitch shift
2024-01-20 Pitch change
2024-01-22 First version of pitch measure
2024-01-23 Working pitch and note mode
2024-01-24 I think I fixed problem with sound blanking out
    [dsp.c, main.cpp]
2024-02-01 Decently working pitch to usb midi
2024-02-11 Added a stompbox
    [StompBox-B_Cu.gbr, StompBox-B_Mask.gbr, StompBox-B_Paste.gbr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]
2024-02-24 Stompbox JLCPCB
    [StompBox-B_Cu.gbr, StompBox-B_Mask.gbr, StompBox-B_Paste.gbr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]
2024-03-02 Minor code fixes
    [GuitarPico-B_Cu.gbr, GuitarPico-B_Mask.gbr, GuitarPico-B_Paste.gbr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]
2024-03-20 Added support for stomp box
    [GuitarPico-BOM.ods, StompBox.kicad_sch]
2024-04-28 Refactored dsp structures into two parts
    [GuitarPico-B_Cu.gbr, GuitarPico-B_Mask.gbr, GuitarPico-B_Paste.gbr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]
2024-07-27 Backported fixed to DSP library from synthesizer
    [dsp.c, guitarpico.h]
2025-01-04 Moved to new computer
    [GuitarPico-B_Cu.gbr, GuitarPico-B_Mask.gbr, GuitarPico-B_Paste.gbr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]
2026-01-17 Added STL file for pedal enclosure
